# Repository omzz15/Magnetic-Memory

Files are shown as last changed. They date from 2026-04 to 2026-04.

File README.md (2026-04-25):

*Note: Any time I say MAD, I am refering to the memory address.

# Overview

Magnetic-core memory was an early form of non-volatile random access memory (RAM) used in early computing, notably the Apollo Guidance Computers. I am working with a friend to create our own magnetic core memory to interface with an 8-bit computer. This repository contains the code, schematics, and PCBs we make. Currently, we have made the schematic and PCB for the logic component of the memory as well as code to emulate the rest of the memory and interface with computers through serial. This is still a work in progress and has a long way to go but I thought I would share what I have.

TODO write updated docs

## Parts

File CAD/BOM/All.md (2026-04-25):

## Resistors(0603)
1. 10k: 32
2. 5.1k: 2
3. 1k: 2
4. 240: 43
5. 11: 16
6. 1K5: 24
7. 1K2: 16
8. 1K8: 16

9. 10: 32

## Capacitors(0603)
1. 220p: 2
2. 1000p: 2
3. 1u: 17
4. 10u: 40

## Other
1. 74HC4514PW,118(demux): 2
2. 74AHC123AD,118(multivibrator): 2
3. SN74LVC1G08DBVR-EV(AND): 1
4. MC74VHC1G32DFT1G-L22038(OR): 1
5. GSFC0201 (N-CH MOS)(SOT-23): 48
6. DMC2710UDW-7(MOSFET N/P-CH)(SOT-363): 64
7. SN74HCS32PWR(OR 4ch): 2
8. SN74AHC240PWR(8-Bit inverter): 1
9. HEF4043BT,653(SR latch 4ch): 2
10. LM393A-SR (Comparator)(8-SOIC 3.9mm): 8

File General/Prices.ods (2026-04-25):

Buying
Function | Part # | Part Description | Digikey # | Unit Price | Qty. | Total | Supply Capacitance | Grand Total: | 5.66
8 Bit Inverter | SN74AHC240PWR | 2 x 4 bit inverter w/ tri state output | 296-4582-1-ND | $0.53 | 1 | $0.53
2x 4 Bit Memory Register & Demux | CD4514BM96 | 4 Bit Demux w/ latch | 296-31529-1-ND | $0.91 | 2 | $1.82
8 Bit Latch / Register & Tri-state Buffer | HEF4043BT,653 | 4 Bit SR Latch w/ 3 state output | 1727-1799-1-ND | $0.58 | 2 | $1.16
2x Pulse EN & Pulse Reset | 74AHC123AD,118 | 2 ch Monostable Multivibrator | 1727-7290-1-ND | $0.41 | 2 | $0.82
Y EN Trigger Delay Resistor | ERA-6AEB181V | 180 ohm 1/8 watt 0805 resistor 0.1% tol | P180DACT-ND | $0.13 | 1 | $0.13
Y EN Trigger Delay Capacitor | GMC21CG102F50NT | 1nF 0805 MLCC 1% tol | 4713-GMC21CG102F50NTCT-ND | $0.13 | 1 | $0.13
X/Y EN Pulse Resistor | ERA-6AEB471V | 470 ohm 1/8 watt 0805 resistor 0.1% tol | P470DACT-ND | $0.13 | 2 | $0.26
X/Y EN Pulse Capacitor | C0805C103J5RAC7210 | 10nF 0805 MLCC 5% tol | 399-17616-1-ND | $0.10 | 2 | $0.20
SR Reset Pulse Resistor | ERA-6AEB222V | 2.2k ohm 1/8 watt 0805 resistor 0.1% tol | P2.2KDACT-ND | $0.13 | 1 | $0.13
SR Reset Pulse Capacitor | C0805C101G5HAC7800 | 0.1nF 0805 MLCC 2% tol | 399-C0805C101G5HAC7800CT-ND | $0.14 | 1 | $0.14
EN Pulse Trigger | SN74LVC1G32DBVR | High power OR Gate | 296-9847-1-ND | $0.34 | 1 | $0.34
Finding
 |  | 2.2k ohm potentiometer (0.1in spacing) |  |  | 1
 |  | 1.5k ohm potentiometer (0.1in spacing) |  |  | 2
 |  | 10nf 0603 power caps
Tri-state Buffer | M74HCT245TTR | 8 Bit Transceiver | 497-8195-1-ND | $0.34 | 0 | $0.00

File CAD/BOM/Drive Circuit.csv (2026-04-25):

Id | Designator | Footprint | Quantity | Designation | Supplier and ref
1 | Q52,Q10,Q82,Q46,Q79,Q19,Q34,Q16,Q25,Q28,Q49,Q67,Q61,Q1,Q73,Q70,Q7,Q76,Q64,Q88,Q31,Q4,Q43,Q58,Q13,Q40,Q37,Q85,Q55,Q91,Q22,Q94 | SOT-23 | 32 | 2N7002E
2 | Y1,X1,X2,Y2 | PinHeader_1x16_P2.54mm_Vertical | 4 | Conn_01x16
3 | Q77,Q81,Q24,Q57,Q44,Q78,Q87,Q54,Q5,Q93,Q51,Q38,Q41,Q11,Q92,Q80,Q60,Q20,Q66,Q53,Q86,Q23,Q35,Q3,Q72,Q36,Q48,Q27,Q18,Q83,Q33,Q14,Q2,Q30,Q21,Q45,Q90,Q89,Q84,Q96,Q9,Q6,Q71,Q17,Q56,Q32,Q8,Q47,Q29,Q15,Q63,Q75,Q68,Q26,Q69,Q59,Q12,Q50,Q65,Q74,Q95,Q62,Q42,Q39 | SOT65P210X110-6N | 64 | DMC2710UDW-7
4 | R14,R10,R26,R32,R27,R19,R17,R31,R24,R30,R23,R22,R18,R12,R25,R3,R6,R20,R7,R2,R9,R8,R4,R34,R28,R5,R29,R1,R33,R21,R11,R16,R13,R15 | R_0603_1608Metric_Pad0.98x0.95mm_HandSolder | 34 | 240
5 | MADX1,MADY2,MADX2,MADY1 | PinHeader_1x08_P2.54mm_Vertical | 4 | Conn_01x08
6 | PWR1,DAT1 | PinHeader_1x02_P2.54mm_Vertical | 2 | Conn_01x02
7 | C29,C2,C8,C32,C23,C28,C15,C10,C16,C19,C21,C17,C20,C5,C7,C6,C30,C11,C27,C4,C12,C31,C22,C1,C24,C14,C18,C3,C26,C13,C25,C9 | C_0603_1608Metric_Pad1.08x0.95mm_HandSolder | 32 | 10u

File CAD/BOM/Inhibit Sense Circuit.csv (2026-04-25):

Id | Designator | Footprint | Quantity | Designation | Supplier and ref
1 | R56,R30,R74,R85,R24,R59,R65,R33,R39,R82,R15,R21,R45,R68,R12,R77 | R_0603_1608Metric_Pad0.98x0.95mm_HandSolder | 16 | 11
2 | IS8,IS1,IS5,IS4,IS7,J2,IS2,IS3,IS6 | PinHeader_1x02_P2.54mm_Vertical | 9 | Conn_01x02
3 | IC3,IC5 | SOP65P640X120-14N | 2 | SN74HCS32PWR
4 | R72,R75,R28,R37,R78,R9,R60,R16,R31,R53,R66,R69,R63,R25,R57,R47,R19,R41,R34,R13,R86,R83,R10,R22 | R_0603_1608Metric_Pad0.98x0.95mm_HandSolder | 24 | 1K5
5 | Q5,Q8,Q1,Q14,Q11,Q7,Q10,Q3,Q2,Q4,Q15,Q13,Q6,Q12,Q16,Q9 | SOT-23 | 16 | 2N7002E
6 | U6,U8,U1,U5,U2,U4,U7,U3 | SO1SOP-8-A_TPK | 8 | LM393
7 | R71,R51,R36,R35,R88,R87,R27,R62,R61,R26,R80,R17,R49,R18,R70,R79 | R_0603_1608Metric_Pad0.98x0.95mm_HandSolder | 16 | 1K2
8 | R64,R55,R76,R38,R20,R84,R43,R11,R32,R29,R67,R14,R23,R73,R58,R81 | R_0603_1608Metric_Pad0.98x0.95mm_HandSolder | 16 | 1K8
9 | R1,R54,R42,R46,R40,R50,R52,R48,R44 | R_0603_1608Metric_Pad0.98x0.95mm_HandSolder | 9 | 240
10 | IC1,IC2 | HEF4043BT653 | 2 | HEF4043BT,653
11 | IC4 | SOP65P640X120-20N | 1 | SN74AHC240PWR
12 | J1 | PinHeader_1x13_P2.54mm_Vertical | 1 | Conn_01x13
13 | C9,C48,C14,C15,C12,C10,C13,C11 | C_0603_1608Metric_Pad1.08x0.95mm_HandSolder | 8 | 10u
14 | C19,C3,C8,C20,C18,C17,C2,C6,C16,C7,C4,C5,C1 | C_0603_1608Metric_Pad1.08x0.95mm_HandSolder | 13 | 1u

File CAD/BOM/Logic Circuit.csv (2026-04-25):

Id | Designator | Footprint | Quantity | Designation | Supplier and ref
1 | R24,R37,R14,R2,R34,R25,R41,R3,R40,R32,R16,R8,R35,R1,R26,R38,R18,R30,R15,R36,R29,R4,R28,R33,R17,R22,R31,R27,R21,R23,R11,R6 | R_0603_1608Metric_Pad0.98x0.95mm_HandSolder | 32 | 10k
2 | C4,C3 | C_0603_1608Metric_Pad1.08x0.95mm_HandSolder | 2 | 220p
3 | C2,C1 | C_0603_1608Metric_Pad1.08x0.95mm_HandSolder | 2 | 1000p
4 | IC3,IC1 | SOP65P640X110-24N | 2 | 74HC4514PW,118
5 | R42,R43 | R_0603_1608Metric_Pad0.98x0.95mm_HandSolder | 2 | 5.1k
6 | IS_OUT1,IN1 | PinHeader_1x13_P2.54mm_Vertical | 2 | Conn_01x13
7 | RV1,RV3,RV2 | Potentiometer_Bourns_3296W_Vertical | 3 | R_Potentiometer
8 | IC5,IC4 | SOIC127P600X175-16N | 2 | 74AHC123AD,118
9 | Y1,X2,Y2,X1 | PinHeader_1x08_P2.54mm_Vertical | 4 | Conn_01x08
10 | C7,C8,C9,C6 | C_0603_1608Metric_Pad1.08x0.95mm_HandSolder | 4 | 1u
11 | D_DAT1 | PinSocket_1x02_P2.54mm_Vertical | 1 | Conn_01x02
12 | PULSE_DBG1 | PinSocket_1x06_P2.54mm_Vertical | 1 | Conn_01x06
13 | R39,R44 | R_0603_1608Metric_Pad0.98x0.95mm_HandSolder | 2 | 1k
14 | U2 | SOT-23-5_HandSoldering | 1 | SN74LVC1G08DBVR-EV
15 | U1 | SOT-353_SC-70-5_Handsoldering | 1 | MC74VHC1G32DFT1G-L22038

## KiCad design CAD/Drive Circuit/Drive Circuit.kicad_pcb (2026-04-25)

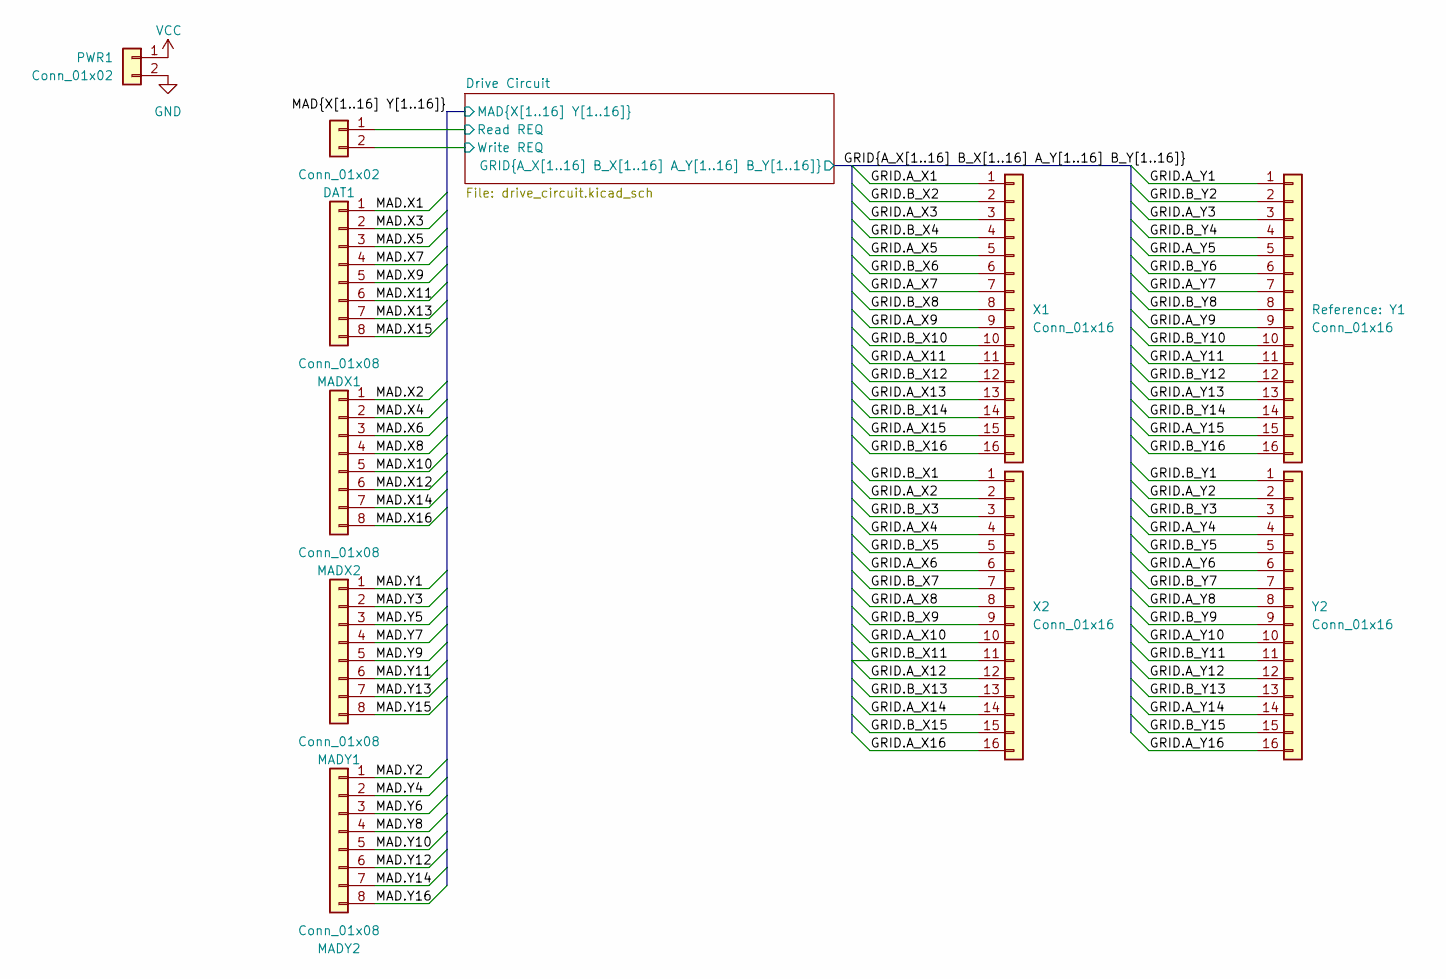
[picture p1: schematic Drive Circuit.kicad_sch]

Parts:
DAT1: Conn_01x02; PinHeader_1x02_P2.54mm_Vertical
MADX1, MADX2: Conn_01x08; PinHeader_1x08_P2.54mm_Vertical
MADY1, MADY2: Conn_01x08; PinHeader_1x08_P2.54mm_Vertical
PWR1: Conn_01x02; PinHeader_1x02_P2.54mm_Vertical
X1, X2: Conn_01x16; PinHeader_1x16_P2.54mm_Vertical
Y1, Y2: Conn_01x16; PinHeader_1x16_P2.54mm_Vertical

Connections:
/Drive Circuit/Read REQ: DAT1.1; also elsewhere on the board
/Drive Circuit/Write REQ: DAT1.2; also elsewhere on the board
/GRID.A_X1: X1.1; also elsewhere on the board
/GRID.A_X2: X2.2; also elsewhere on the board
/GRID.A_X3: X1.3; also elsewhere on the board
/GRID.A_X4: X2.4; also elsewhere on the board
/GRID.A_X5: X1.5; also elsewhere on the board
/GRID.A_X6: X2.6; also elsewhere on the board
/GRID.A_X7: X1.7; also elsewhere on the board
/GRID.A_X8: X2.8; also elsewhere on the board
/GRID.A_X9: X1.9; also elsewhere on the board
/GRID.A_X10: X2.10; also elsewhere on the board
/GRID.A_X11: X1.11; also elsewhere on the board
/GRID.A_X12: X2.12; also elsewhere on the board
/GRID.A_X13: X1.13; also elsewhere on the board
/GRID.A_X14: X2.14; also elsewhere on the board
/GRID.A_X15: X1.15; also elsewhere on the board
/GRID.A_X16: X2.16; also elsewhere on the board
/GRID.A_Y1: Y1.1; also elsewhere on the board
/GRID.A_Y2: Y2.2; also elsewhere on the board
/GRID.A_Y3: Y1.3; also elsewhere on the board
/GRID.A_Y4: Y2.4; also elsewhere on the board
/GRID.A_Y5: Y1.5; also elsewhere on the board
/GRID.A_Y6: Y2.6; also elsewhere on the board
/GRID.A_Y7: Y1.7; also elsewhere on the board
/GRID.A_Y8: Y2.8; also elsewhere on the board
/GRID.A_Y9: Y1.9; also elsewhere on the board
/GRID.A_Y10: Y2.10; also elsewhere on the board
/GRID.A_Y11: Y1.11; also elsewhere on the board
/GRID.A_Y12: Y2.12; also elsewhere on the board
/GRID.A_Y13: Y1.13; also elsewhere on the board
/GRID.A_Y14: Y2.14; also elsewhere on the board
/GRID.A_Y15: Y1.15; also elsewhere on the board
/GRID.A_Y16: Y2.16; also elsewhere on the board
/GRID.B_X1: X2.1; also elsewhere on the board
/GRID.B_X2: X1.2; also elsewhere on the board
/GRID.B_X3: X2.3; also elsewhere on the board
/GRID.B_X4: X1.4; also elsewhere on the board
/GRID.B_X5: X2.5; also elsewhere on the board
/GRID.B_X6: X1.6; also elsewhere on the board
/GRID.B_X7: X2.7; also elsewhere on the board
/GRID.B_X8: X1.8; also elsewhere on the board
/GRID.B_X9: X2.9; also elsewhere on the board
/GRID.B_X10: X1.10; also elsewhere on the board
/GRID.B_X11: X2.11; also elsewhere on the board
/GRID.B_X12: X1.12; also elsewhere on the board
/GRID.B_X13: X2.13; also elsewhere on the board
/GRID.B_X14: X1.14; also elsewhere on the board
/GRID.B_X15: X2.15; also elsewhere on the board
/GRID.B_X16: X1.16; also elsewhere on the board
/GRID.B_Y1: Y2.1; also elsewhere on the board
/GRID.B_Y2: Y1.2; also elsewhere on the board
/GRID.B_Y3: Y2.3; also elsewhere on the board
/GRID.B_Y4: Y1.4; also elsewhere on the board
/GRID.B_Y5: Y2.5; also elsewhere on the board
/GRID.B_Y6: Y1.6; also elsewhere on the board
/GRID.B_Y7: Y2.7; also elsewhere on the board
/GRID.B_Y8: Y1.8; also elsewhere on the board
/GRID.B_Y9: Y2.9; also elsewhere on the board
/GRID.B_Y10: Y1.10; also elsewhere on the board
/GRID.B_Y11: Y2.11; also elsewhere on the board
/GRID.B_Y12: Y1.12; also elsewhere on the board
/GRID.B_Y13: Y2.13; also elsewhere on the board
/GRID.B_Y14: Y1.14; also elsewhere on the board
/GRID.B_Y15: Y2.15; also elsewhere on the board
/GRID.B_Y16: Y1.16; also elsewhere on the board
/MAD.X1: MADX1.1; also elsewhere on the board
/MAD.X2: MADX2.1; also elsewhere on the board
/MAD.X3: MADX1.2; also elsewhere on the board
/MAD.X4: MADX2.2; also elsewhere on the board
/MAD.X5: MADX1.3; also elsewhere on the board
/MAD.X6: MADX2.3; also elsewhere on the board
/MAD.X7: MADX1.4; also elsewhere on the board
/MAD.X8: MADX2.4; also elsewhere on the board
/MAD.X9: MADX1.5; also elsewhere on the board
/MAD.X10: MADX2.5; also elsewhere on the board
/MAD.X11: MADX1.6; also elsewhere on the board
/MAD.X12: MADX2.6; also elsewhere on the board
/MAD.X13: MADX1.7; also elsewhere on the board
/MAD.X14: MADX2.7; also elsewhere on the board
/MAD.X15: MADX1.8; also elsewhere on the board
/MAD.X16: MADX2.8; also elsewhere on the board
/MAD.Y1: MADY1.1; also elsewhere on the board
/MAD.Y2: MADY2.1; also elsewhere on the board
/MAD.Y3: MADY1.2; also elsewhere on the board
/MAD.Y4: MADY2.2; also elsewhere on the board
/MAD.Y5: MADY1.3; also elsewhere on the board
/MAD.Y6: MADY2.3; also elsewhere on the board
/MAD.Y7: MADY1.4; also elsewhere on the board
/MAD.Y8: MADY2.4; also elsewhere on the board
/MAD.Y9: MADY1.5; also elsewhere on the board
/MAD.Y10: MADY2.5; also elsewhere on the board
/MAD.Y11: MADY1.6; also elsewhere on the board
/MAD.Y12: MADY2.6; also elsewhere on the board
/MAD.Y13: MADY1.7; also elsewhere on the board
/MAD.Y14: MADY2.7; also elsewhere on the board
/MAD.Y15: MADY1.8; also elsewhere on the board
/MAD.Y16: MADY2.8; also elsewhere on the board
GND: PWR1.2; also elsewhere on the board
VCC: PWR1.1; also elsewhere on the board

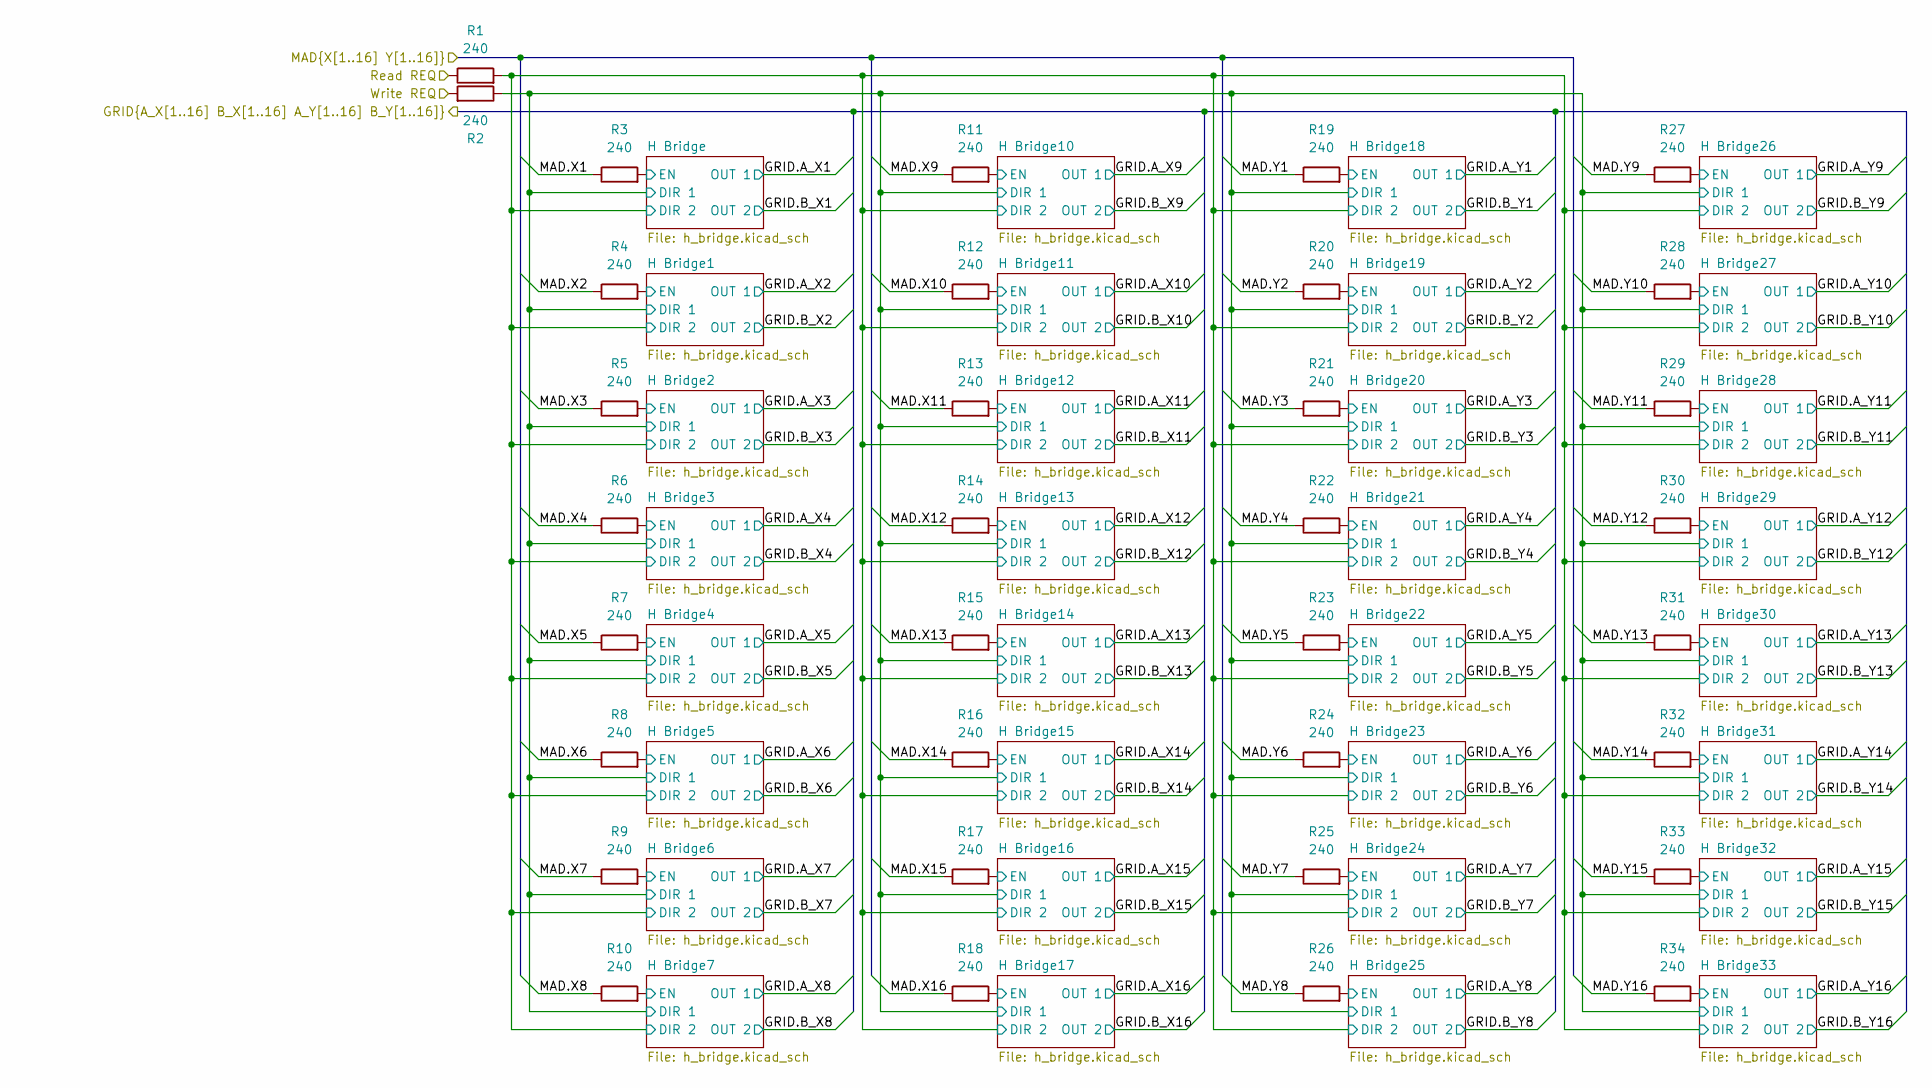
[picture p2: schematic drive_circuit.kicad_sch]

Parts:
R1, R2, R3, R4, R5, R6, R7, R8, R9, R10, R11, R12, R13, R14, R15, R16, R17, R18, R19, R20, R21, R22, R23, R24, R25, R26, R27, R28, R29, R30, R31, R32, R33, R34: 240; R_0603_1608Metric_Pad0.98x0.95mm_HandSolder

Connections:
/Drive Circuit/H Bridge1/EN: R4.2; also elsewhere on the board
/Drive Circuit/H Bridge2/EN: R5.2; also elsewhere on the board
/Drive Circuit/H Bridge3/EN: R6.2; also elsewhere on the board
/Drive Circuit/H Bridge4/EN: R7.2; also elsewhere on the board
/Drive Circuit/H Bridge5/EN: R8.2; also elsewhere on the board
/Drive Circuit/H Bridge6/EN: R9.2; also elsewhere on the board
/Drive Circuit/H Bridge7/EN: R10.2; also elsewhere on the board
/Drive Circuit/H Bridge10/EN: R11.2; also elsewhere on the board
/Drive Circuit/H Bridge11/EN: R12.2; also elsewhere on the board
/Drive Circuit/H Bridge12/EN: R13.2; also elsewhere on the board
/Drive Circuit/H Bridge13/EN: R14.2; also elsewhere on the board
/Drive Circuit/H Bridge14/EN: R15.2; also elsewhere on the board
/Drive Circuit/H Bridge15/EN: R16.2; also elsewhere on the board
/Drive Circuit/H Bridge16/EN: R17.2; also elsewhere on the board
/Drive Circuit/H Bridge17/EN: R18.2; also elsewhere on the board
/Drive Circuit/H Bridge18/EN: R19.2; also elsewhere on the board
/Drive Circuit/H Bridge19/EN: R20.2; also elsewhere on the board
/Drive Circuit/H Bridge20/EN: R21.2; also elsewhere on the board
/Drive Circuit/H Bridge21/EN: R22.2; also elsewhere on the board
/Drive Circuit/H Bridge22/EN: R23.2; also elsewhere on the board
/Drive Circuit/H Bridge23/EN: R24.2; also elsewhere on the board
/Drive Circuit/H Bridge24/EN: R25.2; also elsewhere on the board
/Drive Circuit/H Bridge25/EN: R26.2; also elsewhere on the board
/Drive Circuit/H Bridge26/EN: R27.2; also elsewhere on the board
/Drive Circuit/H Bridge27/EN: R28.2; also elsewhere on the board
/Drive Circuit/H Bridge28/EN: R29.2; also elsewhere on the board
/Drive Circuit/H Bridge29/EN: R30.2; also elsewhere on the board
/Drive Circuit/H Bridge30/EN: R31.2; also elsewhere on the board
/Drive Circuit/H Bridge31/EN: R32.2; also elsewhere on the board
/Drive Circuit/H Bridge32/EN: R33.2; also elsewhere on the board
/Drive Circuit/H Bridge33/EN: R34.2; also elsewhere on the board
/Drive Circuit/H Bridge/DIR 1: R2.1; also elsewhere on the board
/Drive Circuit/H Bridge/DIR 2: R1.2; also elsewhere on the board
/Drive Circuit/H Bridge/EN: R3.2; also elsewhere on the board
/Drive Circuit/Read REQ: R1.1; also elsewhere on the board
/Drive Circuit/Write REQ: R2.2; also elsewhere on the board
/MAD.X1: R3.1; also elsewhere on the board
/MAD.X2: R4.1; also elsewhere on the board
/MAD.X3: R5.1; also elsewhere on the board
/MAD.X4: R6.1; also elsewhere on the board
/MAD.X5: R7.1; also elsewhere on the board
/MAD.X6: R8.1; also elsewhere on the board
/MAD.X7: R9.1; also elsewhere on the board
/MAD.X8: R10.1; also elsewhere on the board
/MAD.X9: R11.1; also elsewhere on the board
/MAD.X10: R12.1; also elsewhere on the board
/MAD.X11: R13.1; also elsewhere on the board
/MAD.X12: R14.1; also elsewhere on the board
/MAD.X13: R15.1; also elsewhere on the board
/MAD.X14: R16.1; also elsewhere on the board
/MAD.X15: R17.1; also elsewhere on the board
/MAD.X16: R18.1; also elsewhere on the board
/MAD.Y1: R19.1; also elsewhere on the board
/MAD.Y2: R20.1; also elsewhere on the board
/MAD.Y3: R21.1; also elsewhere on the board
/MAD.Y4: R22.1; also elsewhere on the board
/MAD.Y5: R23.1; also elsewhere on the board
/MAD.Y6: R24.1; also elsewhere on the board
/MAD.Y7: R25.1; also elsewhere on the board
/MAD.Y8: R26.1; also elsewhere on the board
/MAD.Y9: R27.1; also elsewhere on the board
/MAD.Y10: R28.1; also elsewhere on the board
/MAD.Y11: R29.1; also elsewhere on the board
/MAD.Y12: R30.1; also elsewhere on the board
/MAD.Y13: R31.1; also elsewhere on the board
/MAD.Y14: R32.1; also elsewhere on the board
/MAD.Y15: R33.1; also elsewhere on the board
/MAD.Y16: R34.1; also elsewhere on the board

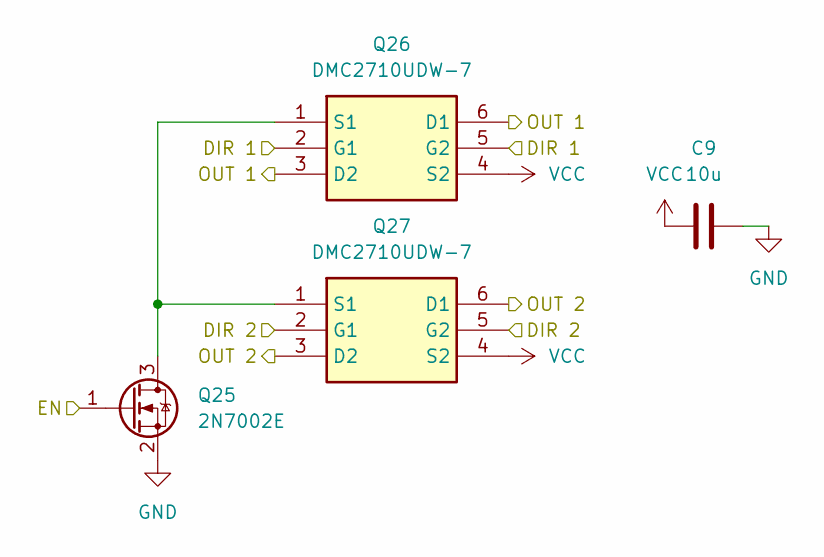
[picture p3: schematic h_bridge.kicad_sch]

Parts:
C9: 10u; C_0603_1608Metric_Pad1.08x0.95mm_HandSolder
Q25: 2N7002E; SOT-23
Q26, Q27: DMC2710UDW-7; SOT65P210X110-6N; Mouser Part Number 621-DMC2710UDW-7

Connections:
/Drive Circuit/H Bridge11/EN: Q25.1 (G); also elsewhere on the board
/Drive Circuit/H Bridge/DIR 1: Q26.2 (G1), Q26.5 (G2); also elsewhere on the board
/Drive Circuit/H Bridge/DIR 2: Q27.2 (G1), Q27.5 (G2); also elsewhere on the board
/GRID.A_X10: Q26.3 (D2), Q26.6 (D1); also elsewhere on the board
/GRID.B_X10: Q27.3 (D2), Q27.6 (D1); also elsewhere on the board
GND: C9.1, Q25.2 (S); also elsewhere on the board
unnamed: Q25.3 (D), Q26.1 (S1), Q27.1 (S1)
VCC: C9.2, Q26.4 (S2), Q27.4 (S2); also elsewhere on the board

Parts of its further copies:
C1, C2, C3, C4, C5, C6, C7, C8, C10, C11, C12, C13, C14, C15, C16, C17, C18, C19, C20, C21, C22, C23, C24, C25, C26, C27, C28, C29, C30, C31, C32: 10u; C_0603_1608Metric_Pad1.08x0.95mm_HandSolder
Q1, Q4, Q7, Q10, Q13, Q16, Q19, Q22, Q28, Q31, Q34, Q37, Q40, Q43, Q46, Q49, Q52, Q55, Q58, Q61, Q64, Q67, Q70, Q73, Q76, Q79, Q82, Q85, Q88, Q91, Q94: 2N7002E; SOT-23
Q2, Q3, Q5, Q6, Q8, Q9, Q11, Q12, Q14, Q15, Q17, Q18, Q20, Q21, Q23, Q24, Q29, Q30, Q32, Q33, Q35, Q36, Q38, Q39, Q41, Q42, Q44, Q45, Q47, Q48, Q50, Q51, Q53, Q54, Q56, Q57, Q59, Q60, Q62, Q63, Q65, Q66, Q68, Q69, Q71, Q72, Q74, Q75, Q77, Q78, Q80, Q81, Q83, Q84, Q86, Q87, Q89, Q90, Q92, Q93, Q95, Q96: DMC2710UDW-7; SOT65P210X110-6N; Mouser Part Number 621-DMC2710UDW-7

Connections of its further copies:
/Drive Circuit/H Bridge1/EN: Q40.1 (G); also elsewhere on the board
/Drive Circuit/H Bridge2/EN: Q34.1 (G); also elsewhere on the board
/Drive Circuit/H Bridge3/EN: Q82.1 (G); also elsewhere on the board
/Drive Circuit/H Bridge4/EN: Q85.1 (G); also elsewhere on the board
/Drive Circuit/H Bridge5/EN: Q79.1 (G); also elsewhere on the board
/Drive Circuit/H Bridge6/EN: Q76.1 (G); also elsewhere on the board
/Drive Circuit/H Bridge7/EN: Q73.1 (G); also elsewhere on the board
/Drive Circuit/H Bridge10/EN: Q31.1 (G); also elsewhere on the board
/Drive Circuit/H Bridge12/EN: Q28.1 (G); also elsewhere on the board
/Drive Circuit/H Bridge13/EN: Q70.1 (G); also elsewhere on the board
/Drive Circuit/H Bridge14/EN: Q67.1 (G); also elsewhere on the board
/Drive Circuit/H Bridge15/EN: Q88.1 (G); also elsewhere on the board
/Drive Circuit/H Bridge16/EN: Q91.1 (G); also elsewhere on the board
/Drive Circuit/H Bridge17/EN: Q94.1 (G); also elsewhere on the board
/Drive Circuit/H Bridge18/EN: Q13.1 (G); also elsewhere on the board
/Drive Circuit/H Bridge19/EN: Q16.1 (G); also elsewhere on the board
/Drive Circuit/H Bridge20/EN: Q22.1 (G); also elsewhere on the board
/Drive Circuit/H Bridge21/EN: Q19.1 (G); also elsewhere on the board
/Drive Circuit/H Bridge22/EN: Q46.1 (G); also elsewhere on the board
/Drive Circuit/H Bridge23/EN: Q43.1 (G); also elsewhere on the board
/Drive Circuit/H Bridge24/EN: Q52.1 (G); also elsewhere on the board
/Drive Circuit/H Bridge25/EN: Q49.1 (G); also elsewhere on the board
/Drive Circuit/H Bridge26/EN: Q4.1 (G); also elsewhere on the board
/Drive Circuit/H Bridge27/EN: Q1.1 (G); also elsewhere on the board
/Drive Circuit/H Bridge28/EN: Q7.1 (G); also elsewhere on the board
/Drive Circuit/H Bridge29/EN: Q10.1 (G); also elsewhere on the board
/Drive Circuit/H Bridge30/EN: Q55.1 (G); also elsewhere on the board
/Drive Circuit/H Bridge31/EN: Q61.1 (G); also elsewhere on the board
/Drive Circuit/H Bridge32/EN: Q64.1 (G); also elsewhere on the board
/Drive Circuit/H Bridge33/EN: Q58.1 (G); also elsewhere on the board
/Drive Circuit/H Bridge/DIR 1: Q2.2 (G1), Q2.5 (G2), Q5.2 (G1), Q5.5 (G2), Q8.2 (G1), Q8.5 (G2), Q11.2 (G1), Q11.5 (G2), Q14.2 (G1), Q14.5 (G2), Q17.2 (G1), Q17.5 (G2), Q20.2 (G1), Q20.5 (G2), Q23.2 (G1), Q23.5 (G2), Q29.2 (G1), Q29.5 (G2), Q32.2 (G1), Q32.5 (G2), Q35.2 (G1), Q35.5 (G2), Q38.2 (G1), Q38.5 (G2), Q41.2 (G1), Q41.5 (G2), Q44.2 (G1), Q44.5 (G2), Q47.2 (G1), Q47.5 (G2), Q50.2 (G1), Q50.5 (G2), Q53.2 (G1), Q53.5 (G2), Q56.2 (G1), Q56.5 (G2), Q59.2 (G1), Q59.5 (G2), Q62.2 (G1), Q62.5 (G2), Q65.2 (G1), Q65.5 (G2), Q68.2 (G1), Q68.5 (G2), Q71.2 (G1), Q71.5 (G2), Q74.2 (G1), Q74.5 (G2), Q77.2 (G1), Q77.5 (G2), Q80.2 (G1), Q80.5 (G2), Q83.2 (G1), Q83.5 (G2), Q86.2 (G1), Q86.5 (G2), Q89.2 (G1), Q89.5 (G2), Q92.2 (G1), Q92.5 (G2), Q95.2 (G1), Q95.5 (G2); also elsewhere on the board
/Drive Circuit/H Bridge/DIR 2: Q3.2 (G1), Q3.5 (G2), Q6.2 (G1), Q6.5 (G2), Q9.2 (G1), Q9.5 (G2), Q12.2 (G1), Q12.5 (G2), Q15.2 (G1), Q15.5 (G2), Q18.2 (G1), Q18.5 (G2), Q21.2 (G1), Q21.5 (G2), Q24.2 (G1), Q24.5 (G2), Q30.2 (G1), Q30.5 (G2), Q33.2 (G1), Q33.5 (G2), Q36.2 (G1), Q36.5 (G2), Q39.2 (G1), Q39.5 (G2), Q42.2 (G1), Q42.5 (G2), Q45.2 (G1), Q45.5 (G2), Q48.2 (G1), Q48.5 (G2), Q51.2 (G1), Q51.5 (G2), Q54.2 (G1), Q54.5 (G2), Q57.2 (G1), Q57.5 (G2), Q60.2 (G1), Q60.5 (G2), Q63.2 (G1), Q63.5 (G2), Q66.2 (G1), Q66.5 (G2), Q69.2 (G1), Q69.5 (G2), Q72.2 (G1), Q72.5 (G2), Q75.2 (G1), Q75.5 (G2), Q78.2 (G1), Q78.5 (G2), Q81.2 (G1), Q81.5 (G2), Q84.2 (G1), Q84.5 (G2), Q87.2 (G1), Q87.5 (G2), Q90.2 (G1), Q90.5 (G2), Q93.2 (G1), Q93.5 (G2), Q96.2 (G1), Q96.5 (G2); also elsewhere on the board
/Drive Circuit/H Bridge/EN: Q37.1 (G); also elsewhere on the board
/GRID.A_X1: Q38.3 (D2), Q38.6 (D1); also elsewhere on the board
/GRID.A_X2: Q41.3 (D2), Q41.6 (D1); also elsewhere on the board
/GRID.A_X3: Q35.3 (D2), Q35.6 (D1); also elsewhere on the board
/GRID.A_X4: Q83.3 (D2), Q83.6 (D1); also elsewhere on the board
/GRID.A_X5: Q86.3 (D2), Q86.6 (D1); also elsewhere on the board
/GRID.A_X6: Q80.3 (D2), Q80.6 (D1); also elsewhere on the board
/GRID.A_X7: Q77.3 (D2), Q77.6 (D1); also elsewhere on the board
/GRID.A_X8: Q74.3 (D2), Q74.6 (D1); also elsewhere on the board
/GRID.A_X9: Q32.3 (D2), Q32.6 (D1); also elsewhere on the board
/GRID.A_X11: Q29.3 (D2), Q29.6 (D1); also elsewhere on the board
/GRID.A_X12: Q71.3 (D2), Q71.6 (D1); also elsewhere on the board
/GRID.A_X13: Q68.3 (D2), Q68.6 (D1); also elsewhere on the board
/GRID.A_X14: Q89.3 (D2), Q89.6 (D1); also elsewhere on the board
/GRID.A_X15: Q92.3 (D2), Q92.6 (D1); also elsewhere on the board
/GRID.A_X16: Q95.3 (D2), Q95.6 (D1); also elsewhere on the board
/GRID.A_Y1: Q14.3 (D2), Q14.6 (D1); also elsewhere on the board
/GRID.A_Y2: Q17.3 (D2), Q17.6 (D1); also elsewhere on the board
/GRID.A_Y3: Q23.3 (D2), Q23.6 (D1); also elsewhere on the board
/GRID.A_Y4: Q20.3 (D2), Q20.6 (D1); also elsewhere on the board
/GRID.A_Y5: Q47.3 (D2), Q47.6 (D1); also elsewhere on the board
/GRID.A_Y6: Q44.3 (D2), Q44.6 (D1); also elsewhere on the board
/GRID.A_Y7: Q53.3 (D2), Q53.6 (D1); also elsewhere on the board
/GRID.A_Y8: Q50.3 (D2), Q50.6 (D1); also elsewhere on the board
/GRID.A_Y9: Q5.3 (D2), Q5.6 (D1); also elsewhere on the board
/GRID.A_Y10: Q2.3 (D2), Q2.6 (D1); also elsewhere on the board
/GRID.A_Y11: Q8.3 (D2), Q8.6 (D1); also elsewhere on the board
/GRID.A_Y12: Q11.3 (D2), Q11.6 (D1); also elsewhere on the board
/GRID.A_Y13: Q56.3 (D2), Q56.6 (D1); also elsewhere on the board
/GRID.A_Y14: Q62.3 (D2), Q62.6 (D1); also elsewhere on the board
/GRID.A_Y15: Q65.3 (D2), Q65.6 (D1); also elsewhere on the board
/GRID.A_Y16: Q59.3 (D2), Q59.6 (D1); also elsewhere on the board
/GRID.B_X1: Q39.3 (D2), Q39.6 (D1); also elsewhere on the board
/GRID.B_X2: Q42.3 (D2), Q42.6 (D1); also elsewhere on the board
/GRID.B_X3: Q36.3 (D2), Q36.6 (D1); also elsewhere on the board
/GRID.B_X4: Q84.3 (D2), Q84.6 (D1); also elsewhere on the board
/GRID.B_X5: Q87.3 (D2), Q87.6 (D1); also elsewhere on the board
/GRID.B_X6: Q81.3 (D2), Q81.6 (D1); also elsewhere on the board
/GRID.B_X7: Q78.3 (D2), Q78.6 (D1); also elsewhere on the board
/GRID.B_X8: Q75.3 (D2), Q75.6 (D1); also elsewhere on the board
/GRID.B_X9: Q33.3 (D2), Q33.6 (D1); also elsewhere on the board
/GRID.B_X11: Q30.3 (D2), Q30.6 (D1); also elsewhere on the board
/GRID.B_X12: Q72.3 (D2), Q72.6 (D1); also elsewhere on the board
/GRID.B_X13: Q69.3 (D2), Q69.6 (D1); also elsewhere on the board
/GRID.B_X14: Q90.3 (D2), Q90.6 (D1); also elsewhere on the board
/GRID.B_X15: Q93.3 (D2), Q93.6 (D1); also elsewhere on the board
/GRID.B_X16: Q96.3 (D2), Q96.6 (D1); also elsewhere on the board
/GRID.B_Y1: Q15.3 (D2), Q15.6 (D1); also elsewhere on the board
/GRID.B_Y2: Q18.3 (D2), Q18.6 (D1); also elsewhere on the board
/GRID.B_Y3: Q24.3 (D2), Q24.6 (D1); also elsewhere on the board
/GRID.B_Y4: Q21.3 (D2), Q21.6 (D1); also elsewhere on the board
/GRID.B_Y5: Q48.3 (D2), Q48.6 (D1); also elsewhere on the board
/GRID.B_Y6: Q45.3 (D2), Q45.6 (D1); also elsewhere on the board
/GRID.B_Y7: Q54.3 (D2), Q54.6 (D1); also elsewhere on the board
/GRID.B_Y8: Q51.3 (D2), Q51.6 (D1); also elsewhere on the board
/GRID.B_Y9: Q6.3 (D2), Q6.6 (D1); also elsewhere on the board
/GRID.B_Y10: Q3.3 (D2), Q3.6 (D1); also elsewhere on the board
/GRID.B_Y11: Q9.3 (D2), Q9.6 (D1); also elsewhere on the board
/GRID.B_Y12: Q12.3 (D2), Q12.6 (D1); also elsewhere on the board
/GRID.B_Y13: Q57.3 (D2), Q57.6 (D1); also elsewhere on the board
/GRID.B_Y14: Q63.3 (D2), Q63.6 (D1); also elsewhere on the board
/GRID.B_Y15: Q66.3 (D2), Q66.6 (D1); also elsewhere on the board
/GRID.B_Y16: Q60.3 (D2), Q60.6 (D1); also elsewhere on the board
GND: C1.1, C2.1, C3.1, C4.1, C5.1, C6.1, C7.1, C8.1, C10.1, C11.1, C12.1, C13.1, C14.1, C15.1, C16.1, C17.1, C18.1, C19.1, C20.1, C21.1, C22.1, C23.1, C24.1, C25.1, C26.1, C27.1, C28.1, C29.1, C30.1, C31.1, C32.1, Q1.2 (S), Q4.2 (S), Q7.2 (S), Q10.2 (S), Q13.2 (S), Q16.2 (S), Q19.2 (S), Q22.2 (S), Q28.2 (S), Q31.2 (S), Q34.2 (S), Q37.2 (S), Q40.2 (S), Q43.2 (S), Q46.2 (S), Q49.2 (S), Q52.2 (S), Q55.2 (S), Q58.2 (S), Q61.2 (S), Q64.2 (S), Q67.2 (S), Q70.2 (S), Q73.2 (S), Q76.2 (S), Q79.2 (S), Q82.2 (S), Q85.2 (S), Q88.2 (S), Q91.2 (S), Q94.2 (S); also elsewhere on the board
unnamed: Q1.3 (D), Q2.1 (S1), Q3.1 (S1)
unnamed: Q4.3 (D), Q5.1 (S1), Q6.1 (S1)
unnamed: Q7.3 (D), Q8.1 (S1), Q9.1 (S1)
unnamed: Q10.3 (D), Q11.1 (S1), Q12.1 (S1)
unnamed: Q13.3 (D), Q14.1 (S1), Q15.1 (S1)
unnamed: Q16.3 (D), Q17.1 (S1), Q18.1 (S1)
unnamed: Q19.3 (D), Q20.1 (S1), Q21.1 (S1)
unnamed: Q22.3 (D), Q23.1 (S1), Q24.1 (S1)
unnamed: Q28.3 (D), Q29.1 (S1), Q30.1 (S1)
unnamed: Q31.3 (D), Q32.1 (S1), Q33.1 (S1)
unnamed: Q34.3 (D), Q35.1 (S1), Q36.1 (S1)
unnamed: Q37.3 (D), Q38.1 (S1), Q39.1 (S1)
unnamed: Q40.3 (D), Q41.1 (S1), Q42.1 (S1)
unnamed: Q43.3 (D), Q44.1 (S1), Q45.1 (S1)
unnamed: Q46.3 (D), Q47.1 (S1), Q48.1 (S1)
unnamed: Q49.3 (D), Q50.1 (S1), Q51.1 (S1)
unnamed: Q52.3 (D), Q53.1 (S1), Q54.1 (S1)
unnamed: Q55.3 (D), Q56.1 (S1), Q57.1 (S1)
unnamed: Q58.3 (D), Q59.1 (S1), Q60.1 (S1)
unnamed: Q61.3 (D), Q62.1 (S1), Q63.1 (S1)
unnamed: Q64.3 (D), Q65.1 (S1), Q66.1 (S1)
unnamed: Q67.3 (D), Q68.1 (S1), Q69.1 (S1)
unnamed: Q70.3 (D), Q71.1 (S1), Q72.1 (S1)
unnamed: Q73.3 (D), Q74.1 (S1), Q75.1 (S1)
unnamed: Q76.3 (D), Q77.1 (S1), Q78.1 (S1)
unnamed: Q79.3 (D), Q80.1 (S1), Q81.1 (S1)
unnamed: Q82.3 (D), Q83.1 (S1), Q84.1 (S1)
unnamed: Q85.3 (D), Q86.1 (S1), Q87.1 (S1)
unnamed: Q88.3 (D), Q89.1 (S1), Q90.1 (S1)
unnamed: Q91.3 (D), Q92.1 (S1), Q93.1 (S1)
unnamed: Q94.3 (D), Q95.1 (S1), Q96.1 (S1)
VCC: C1.2, C2.2, C3.2, C4.2, C5.2, C6.2, C7.2, C8.2, C10.2, C11.2, C12.2, C13.2, C14.2, C15.2, C16.2, C17.2, C18.2, C19.2, C20.2, C21.2, C22.2, C23.2, C24.2, C25.2, C26.2, C27.2, C28.2, C29.2, C30.2, C31.2, C32.2, Q2.4 (S2), Q3.4 (S2), Q5.4 (S2), Q6.4 (S2), Q8.4 (S2), Q9.4 (S2), Q11.4 (S2), Q12.4 (S2), Q14.4 (S2), Q15.4 (S2), Q17.4 (S2), Q18.4 (S2), Q20.4 (S2), Q21.4 (S2), Q23.4 (S2), Q24.4 (S2), Q29.4 (S2), Q30.4 (S2), Q32.4 (S2), Q33.4 (S2), Q35.4 (S2), Q36.4 (S2), Q38.4 (S2), Q39.4 (S2), Q41.4 (S2), Q42.4 (S2), Q44.4 (S2), Q45.4 (S2), Q47.4 (S2), Q48.4 (S2), Q50.4 (S2), Q51.4 (S2), Q53.4 (S2), Q54.4 (S2), Q56.4 (S2), Q57.4 (S2), Q59.4 (S2), Q60.4 (S2), Q62.4 (S2), Q63.4 (S2), Q65.4 (S2), Q66.4 (S2), Q68.4 (S2), Q69.4 (S2), Q71.4 (S2), Q72.4 (S2), Q74.4 (S2), Q75.4 (S2), Q77.4 (S2), Q78.4 (S2), Q80.4 (S2), Q81.4 (S2), Q83.4 (S2), Q84.4 (S2), Q86.4 (S2), Q87.4 (S2), Q89.4 (S2), Q90.4 (S2), Q92.4 (S2), Q93.4 (S2), Q95.4 (S2), Q96.4 (S2); also elsewhere on the board

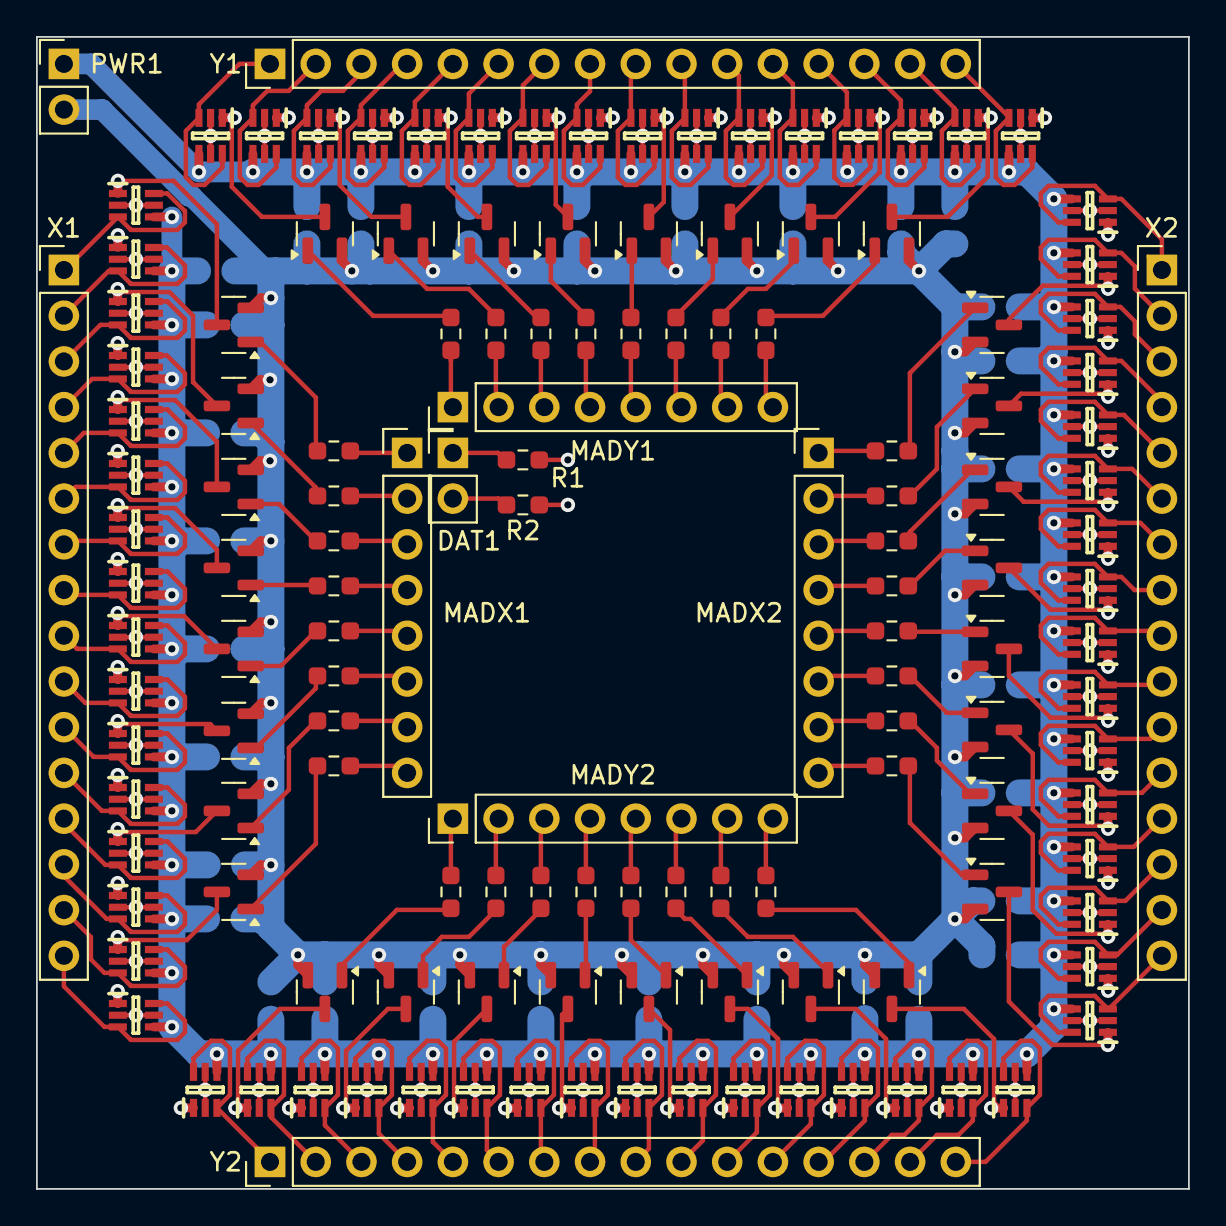
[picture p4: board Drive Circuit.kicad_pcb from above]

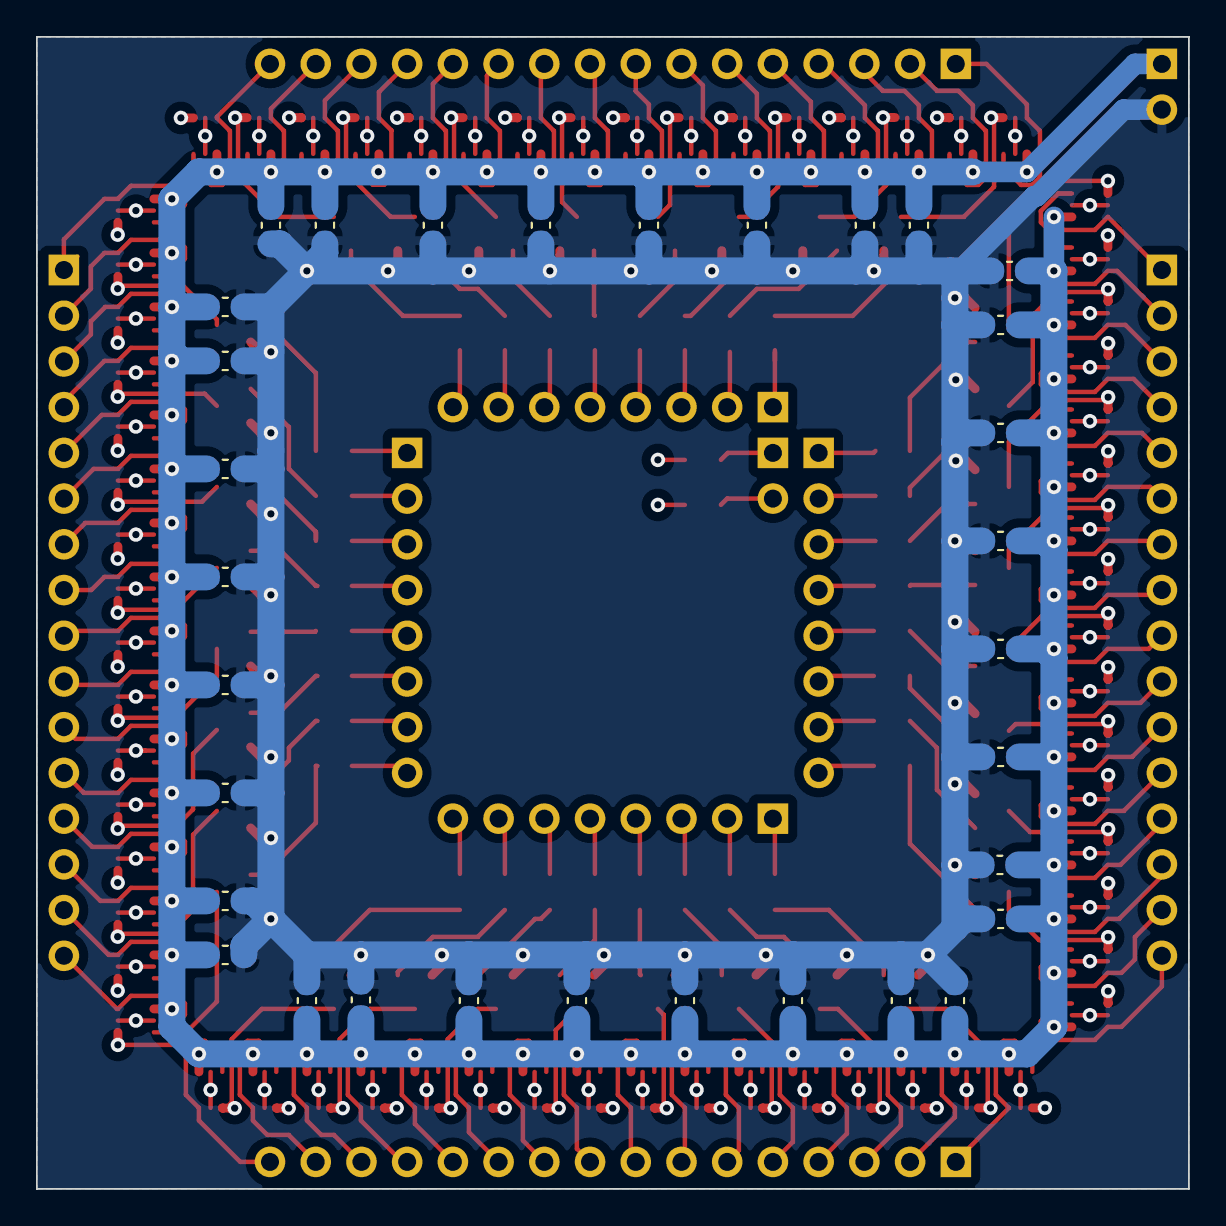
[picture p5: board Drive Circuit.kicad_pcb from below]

Board: 4 copper layers, 64.0 x 64.0 mm, 172 parts (32 on the bottom side), 166 nets.

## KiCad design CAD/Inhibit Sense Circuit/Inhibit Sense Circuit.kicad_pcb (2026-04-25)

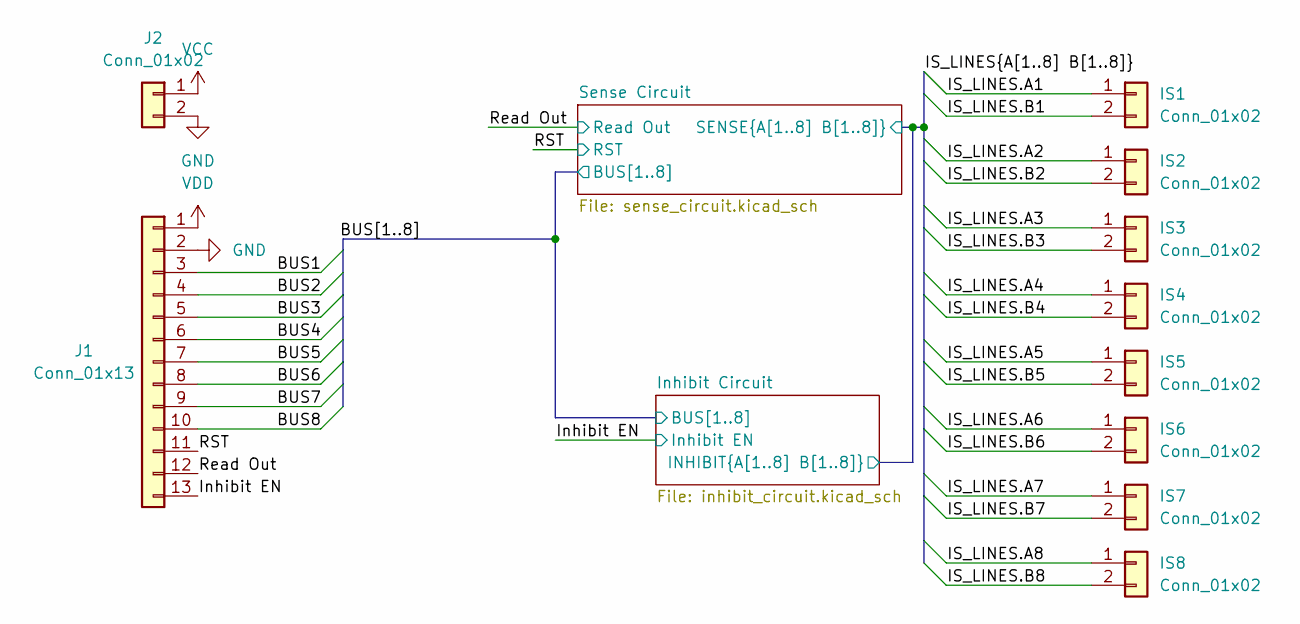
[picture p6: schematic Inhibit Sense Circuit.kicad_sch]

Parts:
IS1, IS2, IS3, IS4, IS5, IS6, IS7, IS8: Conn_01x02; PinHeader_1x02_P2.54mm_Vertical
J1: Conn_01x13; PinHeader_1x13_P2.54mm_Vertical
J2: Conn_01x02; PinHeader_1x02_P2.54mm_Vertical

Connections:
/BUS1: J1.3; also elsewhere on the board
/BUS2: J1.4; also elsewhere on the board
/BUS3: J1.5; also elsewhere on the board
/BUS4: J1.6; also elsewhere on the board
/BUS5: J1.7; also elsewhere on the board
/BUS6: J1.8; also elsewhere on the board
/BUS7: J1.9; also elsewhere on the board
/BUS8: J1.10; also elsewhere on the board
/IS_LINES.A1: IS1.1; also elsewhere on the board
/IS_LINES.A2: IS2.1; also elsewhere on the board
/IS_LINES.A3: IS3.1; also elsewhere on the board
/IS_LINES.A4: IS4.1; also elsewhere on the board
/IS_LINES.A5: IS5.1; also elsewhere on the board
/IS_LINES.A6: IS6.1; also elsewhere on the board
/IS_LINES.A7: IS7.1; also elsewhere on the board
/IS_LINES.A8: IS8.1; also elsewhere on the board
/IS_LINES.B1: IS1.2; also elsewhere on the board
/IS_LINES.B2: IS2.2; also elsewhere on the board
/IS_LINES.B3: IS3.2; also elsewhere on the board
/IS_LINES.B4: IS4.2; also elsewhere on the board
/IS_LINES.B5: IS5.2; also elsewhere on the board
/IS_LINES.B6: IS6.2; also elsewhere on the board
/IS_LINES.B7: IS7.2; also elsewhere on the board
/IS_LINES.B8: IS8.2; also elsewhere on the board
/Inhibit EN: J1.13; also elsewhere on the board
/RST: J1.11; also elsewhere on the board
/Read Out: J1.12; also elsewhere on the board
GND: J1.2, J2.2; also elsewhere on the board
VCC: J2.1; also elsewhere on the board
VDD: J1.1; also elsewhere on the board

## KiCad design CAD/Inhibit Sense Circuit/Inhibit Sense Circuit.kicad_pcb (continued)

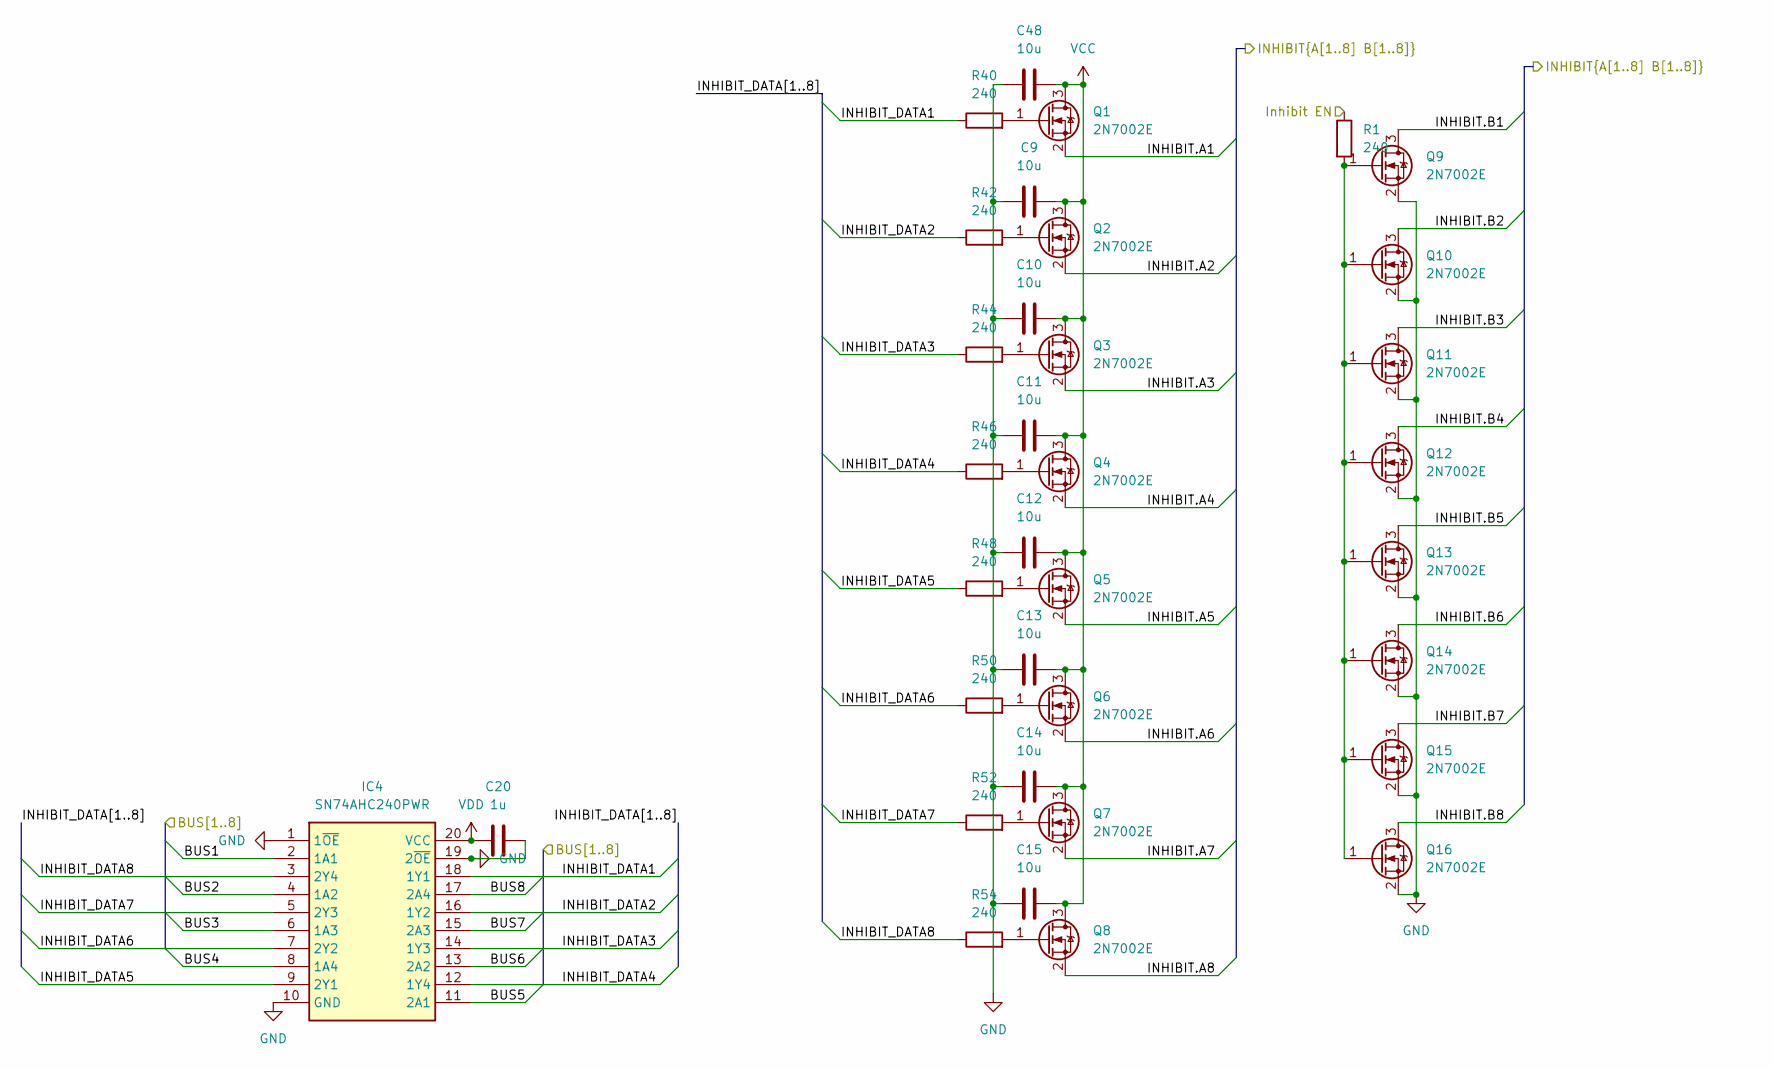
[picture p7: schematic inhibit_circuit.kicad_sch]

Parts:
C9, C10, C11, C12, C13, C14, C15, C48: 10u; C_0603_1608Metric_Pad1.08x0.95mm_HandSolder
C20: 1u; C_0603_1608Metric_Pad1.08x0.95mm_HandSolder
IC4: SN74AHC240PWR; SOP65P640X120-20N; Mouser Part Number 595-SN74AHC240PWR
Q1, Q2, Q3, Q4, Q5, Q6, Q7, Q8, Q9, Q10, Q11, Q12, Q13, Q14, Q15, Q16: 2N7002E; SOT-23
R1, R40, R42, R44, R46, R48, R50, R52, R54: 240; R_0603_1608Metric_Pad0.98x0.95mm_HandSolder

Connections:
/BUS1: IC4.2 (1A1); also elsewhere on the board
/BUS2: IC4.4 (1A2); also elsewhere on the board
/BUS3: IC4.6 (1A3); also elsewhere on the board
/BUS4: IC4.8 (1A4); also elsewhere on the board
/BUS5: IC4.11 (2A1); also elsewhere on the board
/BUS6: IC4.13 (2A2); also elsewhere on the board
/BUS7: IC4.15 (2A3); also elsewhere on the board
/BUS8: IC4.17 (2A4); also elsewhere on the board
/IS_LINES.A1: Q1.2 (S); also elsewhere on the board
/IS_LINES.A2: Q2.2 (S); also elsewhere on the board
/IS_LINES.A3: Q3.2 (S); also elsewhere on the board
/IS_LINES.A4: Q4.2 (S); also elsewhere on the board
/IS_LINES.A5: Q5.2 (S); also elsewhere on the board
/IS_LINES.A6: Q6.2 (S); also elsewhere on the board
/IS_LINES.A7: Q7.2 (S); also elsewhere on the board
/IS_LINES.A8: Q8.2 (S); also elsewhere on the board
/IS_LINES.B1: Q9.3 (D); also elsewhere on the board
/IS_LINES.B2: Q10.3 (D); also elsewhere on the board
/IS_LINES.B3: Q11.3 (D); also elsewhere on the board
/IS_LINES.B4: Q12.3 (D); also elsewhere on the board
/IS_LINES.B5: Q13.3 (D); also elsewhere on the board
/IS_LINES.B6: Q14.3 (D); also elsewhere on the board
/IS_LINES.B7: Q15.3 (D); also elsewhere on the board
/IS_LINES.B8: Q16.3 (D); also elsewhere on the board
/Inhibit Circuit/INHIBIT_DATA1: IC4.18 (1Y1), R40.1
/Inhibit Circuit/INHIBIT_DATA2: IC4.16 (1Y2), R42.1
/Inhibit Circuit/INHIBIT_DATA3: IC4.14 (1Y3), R44.1
/Inhibit Circuit/INHIBIT_DATA4: IC4.12 (1Y4), R46.1
/Inhibit Circuit/INHIBIT_DATA5: IC4.9 (2Y1), R48.1
/Inhibit Circuit/INHIBIT_DATA6: IC4.7 (2Y2), R50.1
/Inhibit Circuit/INHIBIT_DATA7: IC4.5 (2Y3), R52.1
/Inhibit Circuit/INHIBIT_DATA8: IC4.3 (2Y4), R54.1
/Inhibit EN: R1.1; also elsewhere on the board
GND: C9.1, C10.1, C11.1, C12.1, C13.1, C14.1, C15.1, C20.2, C48.1, IC4.1 (1~OE), IC4.10 (GND), IC4.19 (2~OE), Q9.2 (S), Q10.2 (S), Q11.2 (S), Q12.2 (S), Q13.2 (S), Q14.2 (S), Q15.2 (S), Q16.2 (S); also elsewhere on the board
unnamed: Q1.1 (G), R40.2
unnamed: Q2.1 (G), R42.2
unnamed: Q3.1 (G), R44.2
unnamed: Q4.1 (G), R46.2
unnamed: Q5.1 (G), R48.2
unnamed: Q6.1 (G), R50.2
unnamed: Q7.1 (G), R52.2
unnamed: Q8.1 (G), R54.2
unnamed: Q9.1 (G), Q10.1 (G), Q11.1 (G), Q12.1 (G), Q13.1 (G), Q14.1 (G), Q15.1 (G), Q16.1 (G), R1.2
VCC: C9.2, C10.2, C11.2, C12.2, C13.2, C14.2, C15.2, C48.2, Q1.3 (D), Q2.3 (D), Q3.3 (D), Q4.3 (D), Q5.3 (D), Q6.3 (D), Q7.3 (D), Q8.3 (D); also elsewhere on the board
VDD: C20.1, IC4.20 (VCC); also elsewhere on the board

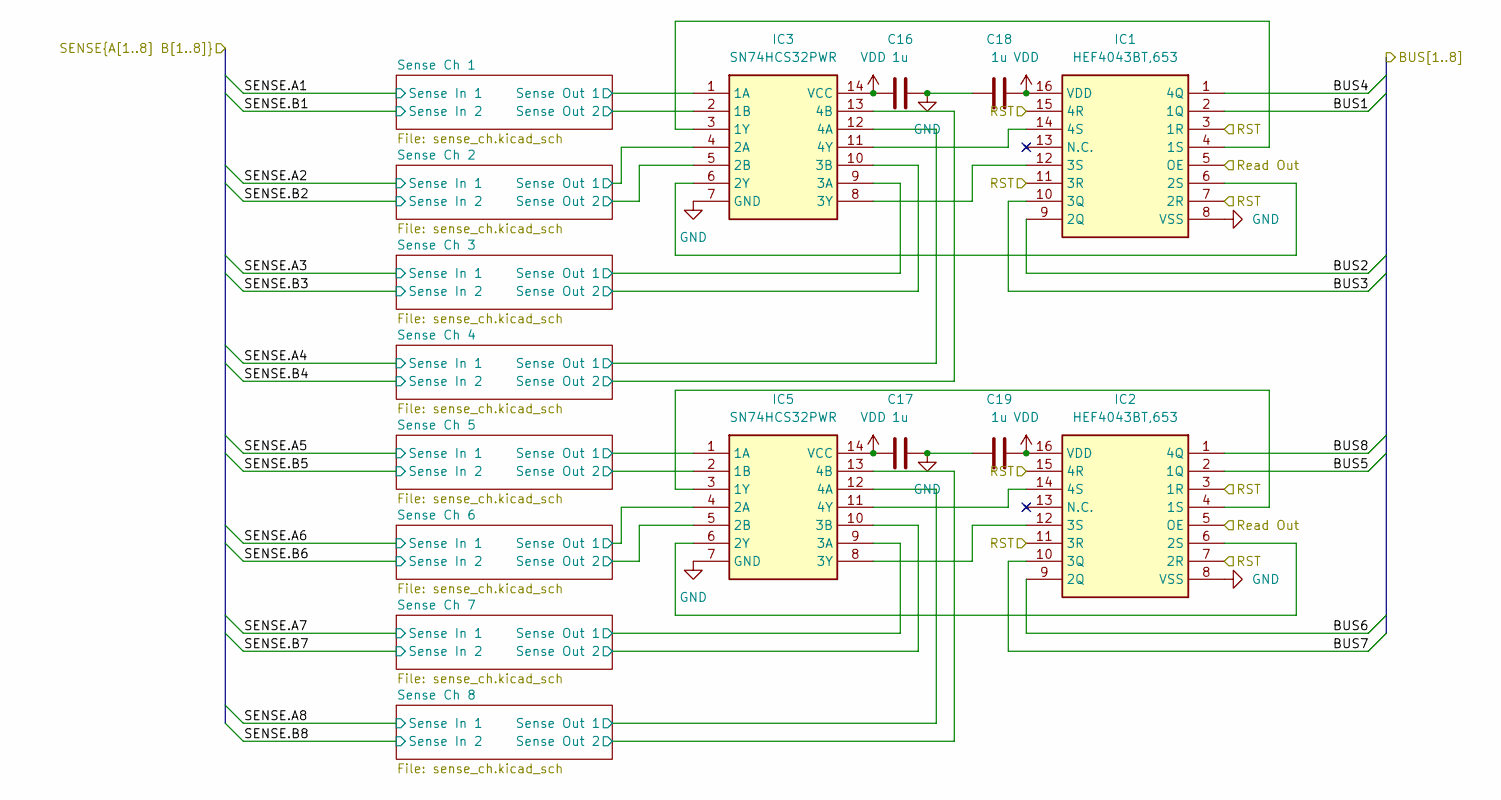
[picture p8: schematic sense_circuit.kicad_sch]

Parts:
C16, C17, C18, C19: 1u; C_0603_1608Metric_Pad1.08x0.95mm_HandSolder
IC1, IC2: HEF4043BT,653; HEF4043BT653; Mouser Part Number 771-HEF4043BT653
IC3, IC5: SN74HCS32PWR; SOP65P640X120-14N; Mouser Part Number 595-SN74HCS32PWR

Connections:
/BUS1: IC1.2 (1Q); also elsewhere on the board
/BUS2: IC1.9 (2Q); also elsewhere on the board
/BUS3: IC1.10 (3Q); also elsewhere on the board
/BUS4: IC1.1 (4Q); also elsewhere on the board
/BUS5: IC2.2 (1Q); also elsewhere on the board
/BUS6: IC2.9 (2Q); also elsewhere on the board
/BUS7: IC2.10 (3Q); also elsewhere on the board
/BUS8: IC2.1 (4Q); also elsewhere on the board
/RST: IC1.3 (1R), IC1.7 (2R), IC1.11 (3R), IC1.15 (4R), IC2.3 (1R), IC2.7 (2R), IC2.11 (3R), IC2.15 (4R); also elsewhere on the board
/Read Out: IC1.5 (OE), IC2.5 (OE); also elsewhere on the board
/Sense Circuit/Sense Ch 1/Sense Out 1: IC3.1 (1A); also elsewhere on the board
/Sense Circuit/Sense Ch 1/Sense Out 2: IC3.2 (1B); also elsewhere on the board
/Sense Circuit/Sense Ch 2/Sense Out 1: IC3.4 (2A); also elsewhere on the board
/Sense Circuit/Sense Ch 2/Sense Out 2: IC3.5 (2B); also elsewhere on the board
/Sense Circuit/Sense Ch 3/Sense Out 1: IC3.9 (3A); also elsewhere on the board
/Sense Circuit/Sense Ch 3/Sense Out 2: IC3.10 (3B); also elsewhere on the board
/Sense Circuit/Sense Ch 4/Sense Out 1: IC3.12 (4A); also elsewhere on the board
/Sense Circuit/Sense Ch 4/Sense Out 2: IC3.13 (4B); also elsewhere on the board
/Sense Circuit/Sense Ch 5/Sense Out 1: IC5.1 (1A); also elsewhere on the board
/Sense Circuit/Sense Ch 5/Sense Out 2: IC5.2 (1B); also elsewhere on the board
/Sense Circuit/Sense Ch 6/Sense Out 1: IC5.4 (2A); also elsewhere on the board
/Sense Circuit/Sense Ch 6/Sense Out 2: IC5.5 (2B); also elsewhere on the board
/Sense Circuit/Sense Ch 7/Sense Out 1: IC5.9 (3A); also elsewhere on the board
/Sense Circuit/Sense Ch 7/Sense Out 2: IC5.10 (3B); also elsewhere on the board
/Sense Circuit/Sense Ch 8/Sense Out 1: IC5.12 (4A); also elsewhere on the board
/Sense Circuit/Sense Ch 8/Sense Out 2: IC5.13 (4B); also elsewhere on the board
GND: C16.2, C17.2, C18.1, C19.1, IC1.8 (VSS), IC2.8 (VSS), IC3.7 (GND), IC5.7 (GND); also elsewhere on the board
unnamed: IC1.4 (1S), IC3.3 (1Y)
unnamed: IC1.6 (2S), IC3.6 (2Y)
unnamed: IC1.12 (3S), IC3.8 (3Y)
unnamed: IC1.14 (4S), IC3.11 (4Y)
unnamed: IC2.4 (1S), IC5.3 (1Y)
unnamed: IC2.6 (2S), IC5.6 (2Y)
unnamed: IC2.12 (3S), IC5.8 (3Y)
unnamed: IC2.14 (4S), IC5.11 (4Y)
VDD: C16.1, C17.1, C18.2, C19.2, IC1.16 (VDD), IC2.16 (VDD), IC3.14 (VCC), IC5.14 (VCC); also elsewhere on the board

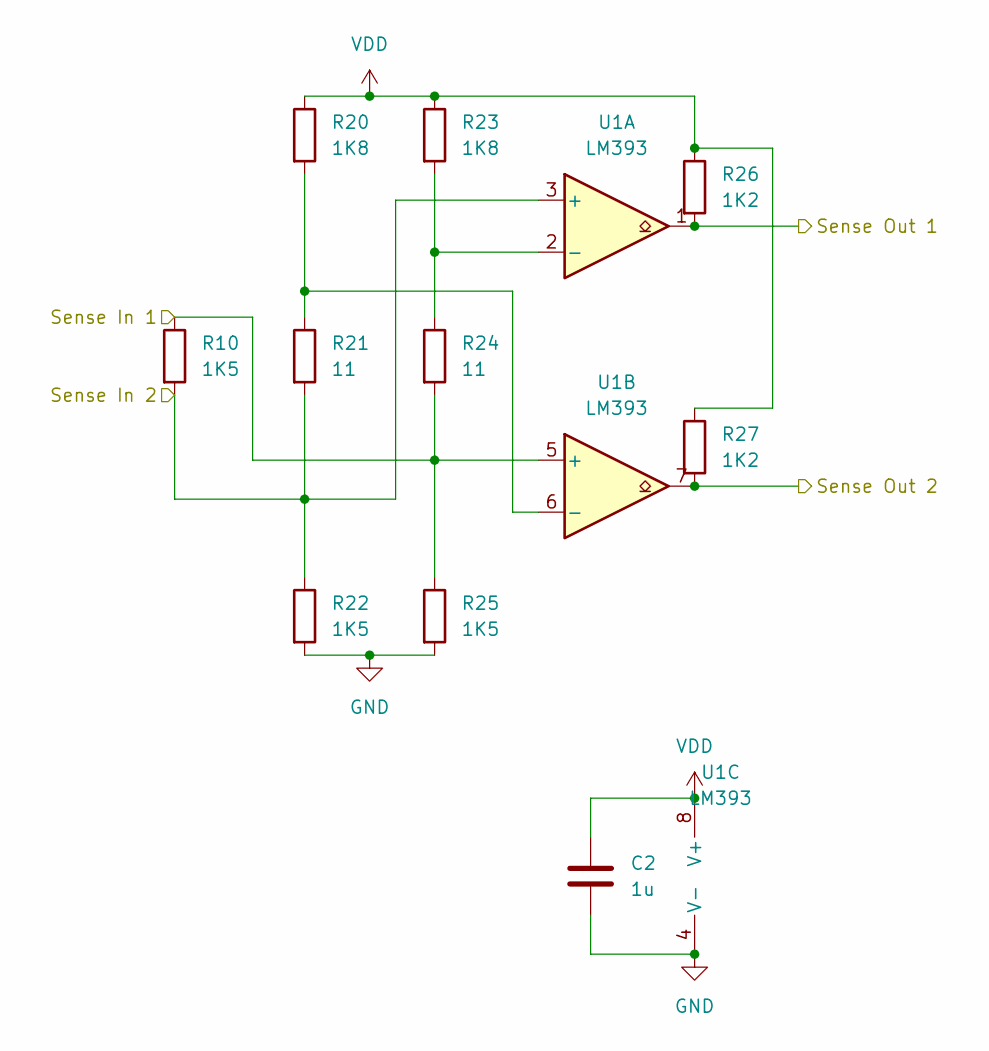
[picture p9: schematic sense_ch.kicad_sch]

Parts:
C2: 1u; C_0603_1608Metric_Pad1.08x0.95mm_HandSolder
R10, R22, R25: 1K5; R_0603_1608Metric_Pad0.98x0.95mm_HandSolder
R20, R23: 1K8; R_0603_1608Metric_Pad0.98x0.95mm_HandSolder
R21, R24: 11; R_0603_1608Metric_Pad0.98x0.95mm_HandSolder
R26, R27: 1K2; R_0603_1608Metric_Pad0.98x0.95mm_HandSolder
U1: LM393; SO1SOP-8-A_TPK

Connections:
/IS_LINES.A1: R10.1, R24.2, R25.1, U1.5 (+); also elsewhere on the board
/IS_LINES.B1: R10.2, R21.2, R22.1, U1.3 (+); also elsewhere on the board
/Sense Circuit/Sense Ch 1/Sense Out 1: R26.2, U1.1; also elsewhere on the board
/Sense Circuit/Sense Ch 1/Sense Out 2: R27.2, U1.7; also elsewhere on the board
GND: C2.2, R22.2, R25.2, U1.4 (V-); also elsewhere on the board
unnamed: R23.2, R24.1, U1.2 (-)
unnamed: R20.2, R21.1, U1.6 (-)
VDD: C2.1, R20.1, R23.1, R26.1, R27.1, U1.8 (V+); also elsewhere on the board

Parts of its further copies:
C1, C3, C4, C5, C6, C7, C8: 1u; C_0603_1608Metric_Pad1.08x0.95mm_HandSolder
R9, R13, R16, R19, R28, R31, R34, R37, R41, R47, R53, R57, R60, R63, R66, R69, R72, R75, R78, R83, R86: 1K5; R_0603_1608Metric_Pad0.98x0.95mm_HandSolder
R11, R14, R29, R32, R38, R43, R55, R58, R64, R67, R73, R76, R81, R84: 1K8; R_0603_1608Metric_Pad0.98x0.95mm_HandSolder
R12, R15, R30, R33, R39, R45, R56, R59, R65, R68, R74, R77, R82, R85: 11; R_0603_1608Metric_Pad0.98x0.95mm_HandSolder
R17, R18, R35, R36, R49, R51, R61, R62, R70, R71, R79, R80, R87, R88: 1K2; R_0603_1608Metric_Pad0.98x0.95mm_HandSolder
U2, U3, U4, U5, U6, U7, U8: LM393; SO1SOP-8-A_TPK

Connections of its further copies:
/IS_LINES.A2: R9.1, R15.2, R16.1, U2.5 (+); also elsewhere on the board
/IS_LINES.A3: R19.1, R33.2, R34.1, U3.5 (+); also elsewhere on the board
/IS_LINES.A4: R28.1, R45.2, R47.1, U4.5 (+); also elsewhere on the board
/IS_LINES.A5: R37.1, R59.2, R60.1, U5.5 (+); also elsewhere on the board
/IS_LINES.A6: R53.1, R68.2, R69.1, U6.5 (+); also elsewhere on the board
/IS_LINES.A7: R63.1, R77.2, R78.1, U7.5 (+); also elsewhere on the board
/IS_LINES.A8: R72.1, R85.2, R86.1, U8.5 (+); also elsewhere on the board
/IS_LINES.B2: R9.2, R12.2, R13.1, U2.3 (+); also elsewhere on the board
/IS_LINES.B3: R19.2, R30.2, R31.1, U3.3 (+); also elsewhere on the board
/IS_LINES.B4: R28.2, R39.2, R41.1, U4.3 (+); also elsewhere on the board
/IS_LINES.B5: R37.2, R56.2, R57.1, U5.3 (+); also elsewhere on the board
/IS_LINES.B6: R53.2, R65.2, R66.1, U6.3 (+); also elsewhere on the board
/IS_LINES.B7: R63.2, R74.2, R75.1, U7.3 (+); also elsewhere on the board
/IS_LINES.B8: R72.2, R82.2, R83.1, U8.3 (+); also elsewhere on the board
/Sense Circuit/Sense Ch 2/Sense Out 1: R17.2, U2.1; also elsewhere on the board
/Sense Circuit/Sense Ch 2/Sense Out 2: R18.2, U2.7; also elsewhere on the board
/Sense Circuit/Sense Ch 3/Sense Out 1: R35.2, U3.1; also elsewhere on the board
/Sense Circuit/Sense Ch 3/Sense Out 2: R36.2, U3.7; also elsewhere on the board
/Sense Circuit/Sense Ch 4/Sense Out 1: R49.2, U4.1; also elsewhere on the board
/Sense Circuit/Sense Ch 4/Sense Out 2: R51.2, U4.7; also elsewhere on the board
/Sense Circuit/Sense Ch 5/Sense Out 1: R61.2, U5.1; also elsewhere on the board
/Sense Circuit/Sense Ch 5/Sense Out 2: R62.2, U5.7; also elsewhere on the board
/Sense Circuit/Sense Ch 6/Sense Out 1: R70.2, U6.1; also elsewhere on the board
/Sense Circuit/Sense Ch 6/Sense Out 2: R71.2, U6.7; also elsewhere on the board
/Sense Circuit/Sense Ch 7/Sense Out 1: R79.2, U7.1; also elsewhere on the board
/Sense Circuit/Sense Ch 7/Sense Out 2: R80.2, U7.7; also elsewhere on the board
/Sense Circuit/Sense Ch 8/Sense Out 1: R87.2, U8.1; also elsewhere on the board
/Sense Circuit/Sense Ch 8/Sense Out 2: R88.2, U8.7; also elsewhere on the board
GND: C1.2, C3.2, C4.2, C5.2, C6.2, C7.2, C8.2, R13.2, R16.2, R31.2, R34.2, R41.2, R47.2, R57.2, R60.2, R66.2, R69.2, R75.2, R78.2, R83.2, R86.2, U2.4 (V-), U3.4 (V-), U4.4 (V-), U5.4 (V-), U6.4 (V-), U7.4 (V-), U8.4 (V-); also elsewhere on the board
unnamed: R14.2, R15.1, U2.2 (-)
unnamed: R11.2, R12.1, U2.6 (-)
unnamed: R32.2, R33.1, U3.2 (-)
unnamed: R29.2, R30.1, U3.6 (-)
unnamed: R43.2, R45.1, U4.2 (-)
unnamed: R38.2, R39.1, U4.6 (-)
unnamed: R58.2, R59.1, U5.2 (-)
unnamed: R55.2, R56.1, U5.6 (-)
unnamed: R67.2, R68.1, U6.2 (-)
unnamed: R64.2, R65.1, U6.6 (-)
unnamed: R76.2, R77.1, U7.2 (-)
unnamed: R73.2, R74.1, U7.6 (-)
unnamed: R84.2, R85.1, U8.2 (-)
unnamed: R81.2, R82.1, U8.6 (-)
VDD: C1.1, C3.1, C4.1, C5.1, C6.1, C7.1, C8.1, R11.1, R14.1, R17.1, R18.1, R29.1, R32.1, R35.1, R36.1, R38.1, R43.1, R49.1, R51.1, R55.1, R58.1, R61.1, R62.1, R64.1, R67.1, R70.1, R71.1, R73.1, R76.1, R79.1, R80.1, R81.1, R84.1, R87.1, R88.1, U2.8 (V+), U3.8 (V+), U4.8 (V+), U5.8 (V+), U6.8 (V+), U7.8 (V+), U8.8 (V+); also elsewhere on the board

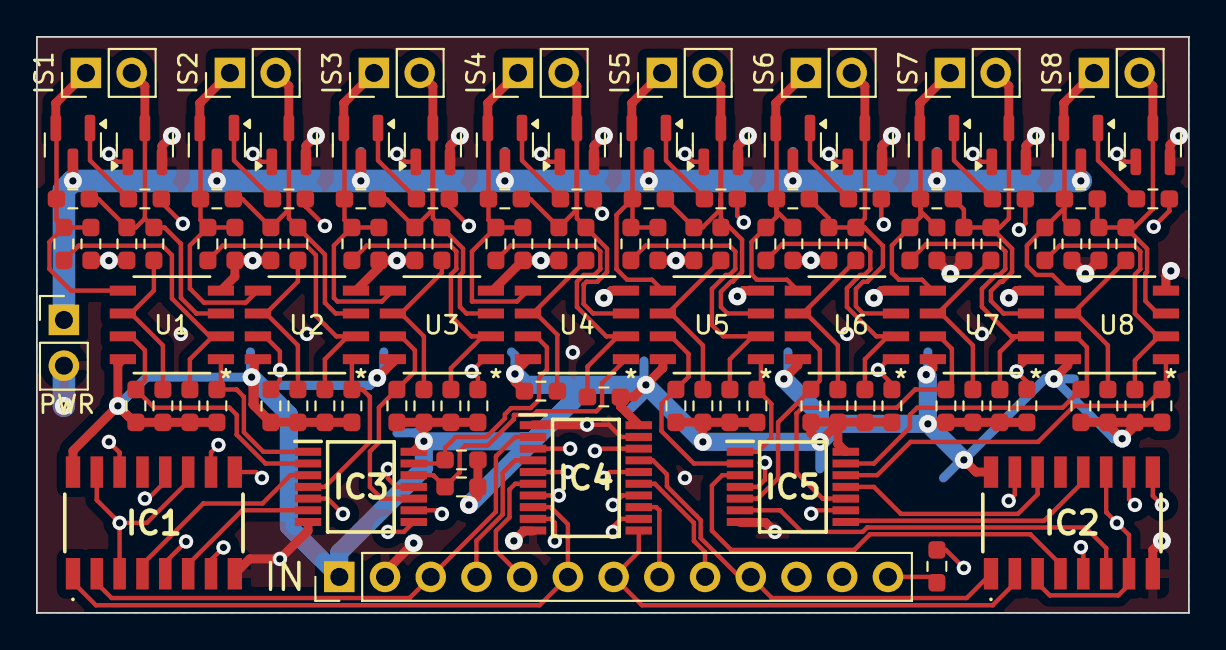
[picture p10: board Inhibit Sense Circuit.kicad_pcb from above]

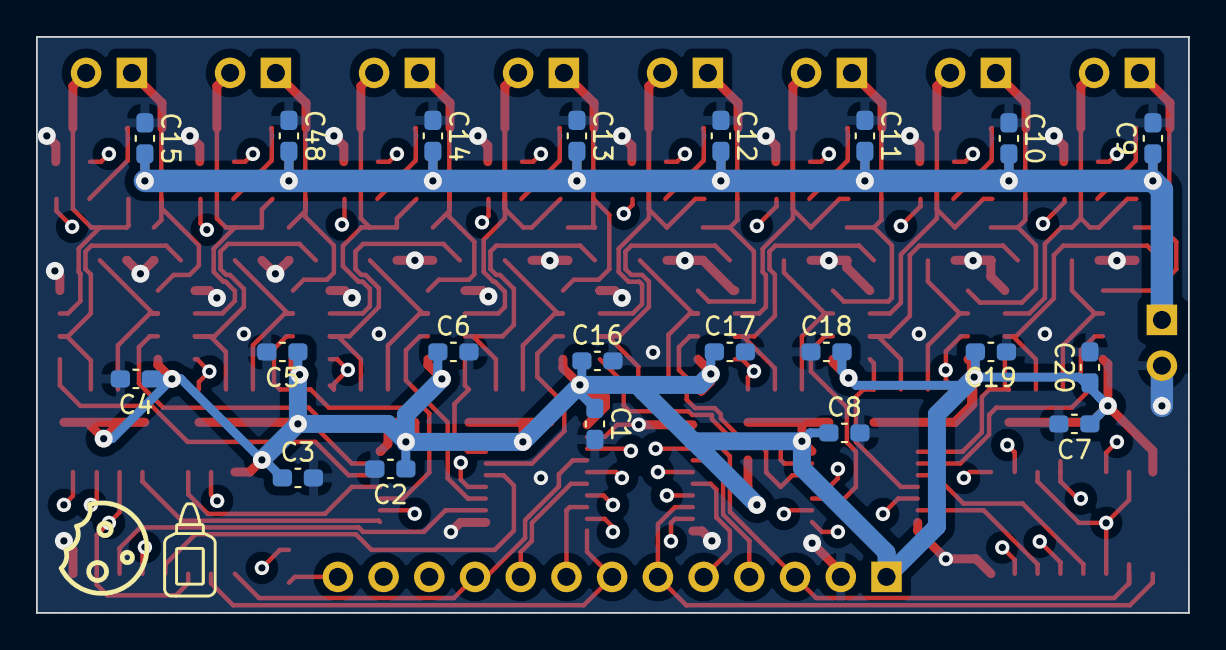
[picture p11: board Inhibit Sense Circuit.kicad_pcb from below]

Board: 4 copper layers, 64.0 x 32.0 mm, 141 parts (21 on the bottom side), 87 nets.

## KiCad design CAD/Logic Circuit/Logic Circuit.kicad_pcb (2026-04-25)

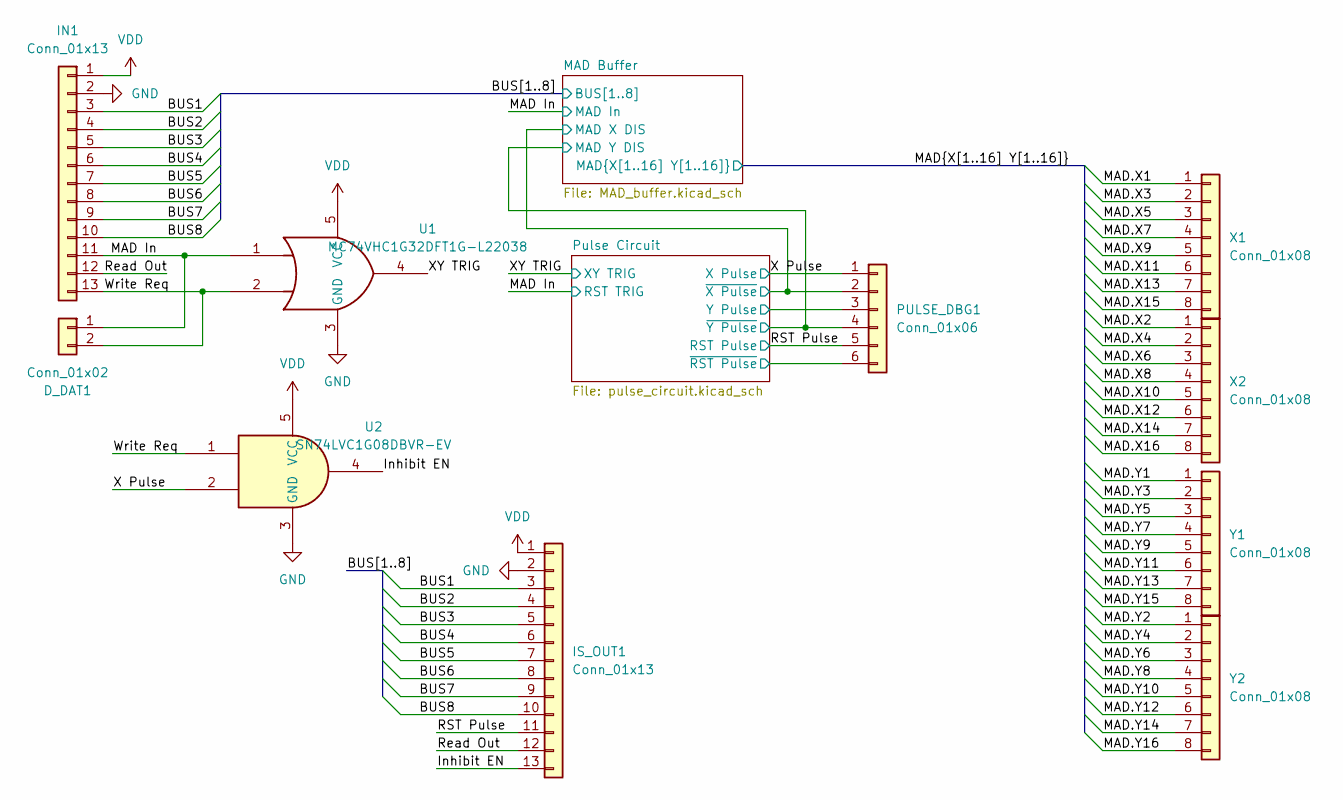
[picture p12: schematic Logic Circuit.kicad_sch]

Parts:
D_DAT1: Conn_01x02; PinSocket_1x02_P2.54mm_Vertical
IN1: Conn_01x13; PinHeader_1x13_P2.54mm_Vertical
IS_OUT1: Conn_01x13; PinHeader_1x13_P2.54mm_Vertical
PULSE_DBG1: Conn_01x06; PinSocket_1x06_P2.54mm_Vertical
U1: MC74VHC1G32DFT1G-L22038; SOT-353_SC-70-5_Handsoldering
U2: SN74LVC1G08DBVR-EV; SOT-23-5_HandSoldering
X1, X2: Conn_01x08; PinHeader_1x08_P2.54mm_Vertical
Y1, Y2: Conn_01x08; PinHeader_1x08_P2.54mm_Vertical

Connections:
/BUS1: IN1.3, IS_OUT1.3; also elsewhere on the board
/BUS2: IN1.4, IS_OUT1.4; also elsewhere on the board
/BUS3: IN1.5, IS_OUT1.5; also elsewhere on the board
/BUS4: IN1.6, IS_OUT1.6; also elsewhere on the board
/BUS5: IN1.7, IS_OUT1.7; also elsewhere on the board
/BUS6: IN1.8, IS_OUT1.8; also elsewhere on the board
/BUS7: IN1.9, IS_OUT1.9; also elsewhere on the board
/BUS8: IN1.10, IS_OUT1.10; also elsewhere on the board
/Inhibit EN: IS_OUT1.13, U2.4
/MAD Buffer/MAD X DIS: PULSE_DBG1.2; also elsewhere on the board
/MAD Buffer/MAD Y DIS: PULSE_DBG1.4; also elsewhere on the board
/MAD In: D_DAT1.1, IN1.11, U1.1; also elsewhere on the board
/MAD.X1: X1.1; also elsewhere on the board
/MAD.X2: X2.1; also elsewhere on the board
/MAD.X3: X1.2; also elsewhere on the board
/MAD.X4: X2.2; also elsewhere on the board
/MAD.X5: X1.3; also elsewhere on the board
/MAD.X6: X2.3; also elsewhere on the board
/MAD.X7: X1.4; also elsewhere on the board
/MAD.X8: X2.4; also elsewhere on the board
/MAD.X9: X1.5; also elsewhere on the board
/MAD.X10: X2.5; also elsewhere on the board
/MAD.X11: X1.6; also elsewhere on the board
/MAD.X12: X2.6; also elsewhere on the board
/MAD.X13: X1.7; also elsewhere on the board
/MAD.X14: X2.7; also elsewhere on the board
/MAD.X15: X1.8; also elsewhere on the board
/MAD.X16: X2.8; also elsewhere on the board
/MAD.Y1: Y1.1; also elsewhere on the board
/MAD.Y2: Y2.1; also elsewhere on the board
/MAD.Y3: Y1.2; also elsewhere on the board
/MAD.Y4: Y2.2; also elsewhere on the board
/MAD.Y5: Y1.3; also elsewhere on the board
/MAD.Y6: Y2.3; also elsewhere on the board
/MAD.Y7: Y1.4; also elsewhere on the board
/MAD.Y8: Y2.4; also elsewhere on the board
/MAD.Y9: Y1.5; also elsewhere on the board
/MAD.Y10: Y2.5; also elsewhere on the board
/MAD.Y11: Y1.6; also elsewhere on the board
/MAD.Y12: Y2.6; also elsewhere on the board
/MAD.Y13: Y1.7; also elsewhere on the board
/MAD.Y14: Y2.7; also elsewhere on the board
/MAD.Y15: Y1.8; also elsewhere on the board
/MAD.Y16: Y2.8; also elsewhere on the board
/Pulse Circuit/Y Pulse: PULSE_DBG1.3; also elsewhere on the board
/Pulse Circuit/~RST Pulse: PULSE_DBG1.6; also elsewhere on the board
/RST Pulse: IS_OUT1.11, PULSE_DBG1.5; also elsewhere on the board
/Read Out: IN1.12, IS_OUT1.12
/Write Req: D_DAT1.2, IN1.13, U1.2, U2.1
/X Pulse: PULSE_DBG1.1, U2.2; also elsewhere on the board
/XY TRIG: U1.4; also elsewhere on the board
GND: IN1.2, IS_OUT1.2, U1.3 (GND), U2.3 (GND); also elsewhere on the board
VDD: IN1.1, IS_OUT1.1, U1.5 (VCC), U2.5 (VCC); also elsewhere on the board


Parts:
C6, C7: 1u; C_0603_1608Metric_Pad1.08x0.95mm_HandSolder
IC1, IC3: 74HC4514PW,118; SOP65P640X110-24N; Mouser Part Number 771-HC4514PW118
R1, R2, R3, R4, R6, R8, R11, R14, R15, R16, R17, R18, R21, R22, R23, R24, R25, R26, R27, R28, R29, R30, R31, R32, R33, R34, R35, R36, R37, R38, R40, R41: 10k; R_0603_1608Metric_Pad0.98x0.95mm_HandSolder

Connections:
/BUS1: IC3.2 (A0); also elsewhere on the board
/BUS2: IC3.3 (A1); also elsewhere on the board
/BUS3: IC3.21 (A2); also elsewhere on the board
/BUS4: IC3.22 (A3); also elsewhere on the board
/BUS5: IC1.2 (A0); also elsewhere on the board
/BUS6: IC1.3 (A1); also elsewhere on the board
/BUS7: IC1.21 (A2); also elsewhere on the board
/BUS8: IC1.22 (A3); also elsewhere on the board
/MAD Buffer/MAD X DIS: IC3.23 (~E); also elsewhere on the board
/MAD Buffer/MAD Y DIS: IC1.23 (~E); also elsewhere on the board
/MAD In: IC1.1 (LE), IC3.1 (LE); also elsewhere on the board
/MAD.X1: IC3.11 (Q0), R3.2; also elsewhere on the board
/MAD.X2: IC3.9 (Q1), R17.2; also elsewhere on the board
/MAD.X3: IC3.10 (Q2), R2.2; also elsewhere on the board
/MAD.X4: IC3.8 (Q3), R14.2; also elsewhere on the board
/MAD.X5: IC3.7 (Q4), R21.2; also elsewhere on the board
/MAD.X6: IC3.6 (Q5), R30.2; also elsewhere on the board
/MAD.X7: IC3.5 (Q6), R23.2; also elsewhere on the board
/MAD.X8: IC3.4 (Q7), R40.2; also elsewhere on the board
/MAD.X9: IC3.18 (Q8), R25.2; also elsewhere on the board
/MAD.X10: IC3.17 (Q9), R35.2; also elsewhere on the board
/MAD.X11: IC3.20 (Q10), R22.2; also elsewhere on the board
/MAD.X12: IC3.19 (Q11), R31.2; also elsewhere on the board
/MAD.X13: IC3.14 (Q12), R27.2; also elsewhere on the board
/MAD.X14: IC3.13 (Q13), R34.2; also elsewhere on the board
/MAD.X15: IC3.16 (Q14), R26.2; also elsewhere on the board
/MAD.X16: IC3.15 (Q15), R36.2; also elsewhere on the board
/MAD.Y1: IC1.11 (Q0), R4.2; also elsewhere on the board
/MAD.Y2: IC1.9 (Q1), R24.2; also elsewhere on the board
/MAD.Y3: IC1.10 (Q2), R1.2; also elsewhere on the board
/MAD.Y4: IC1.8 (Q3), R28.2; also elsewhere on the board
/MAD.Y5: IC1.7 (Q4), R15.2; also elsewhere on the board
/MAD.Y6: IC1.6 (Q5), R32.2; also elsewhere on the board
/MAD.Y7: IC1.5 (Q6), R8.2; also elsewhere on the board
/MAD.Y8: IC1.4 (Q7), R37.2; also elsewhere on the board
/MAD.Y9: IC1.18 (Q8), R11.2; also elsewhere on the board
/MAD.Y10: IC1.17 (Q9), R29.2; also elsewhere on the board
/MAD.Y11: IC1.20 (Q10), R16.2; also elsewhere on the board
/MAD.Y12: IC1.19 (Q11), R41.2; also elsewhere on the board
/MAD.Y13: IC1.14 (Q12), R18.2; also elsewhere on the board
/MAD.Y14: IC1.13 (Q13), R33.2; also elsewhere on the board
/MAD.Y15: IC1.16 (Q14), R6.2; also elsewhere on the board
/MAD.Y16: IC1.15 (Q15), R38.2; also elsewhere on the board
GND: C6.1, C7.1, IC1.12 (GND), IC3.12 (GND), R1.1, R2.1, R3.1, R4.1, R6.1, R8.1, R11.1, R14.1, R15.1, R16.1, R17.1, R18.1, R21.1, R22.1, R23.1, R24.1, R25.1, R26.1, R27.1, R28.1, R29.1, R30.1, R31.1, R32.1, R33.1, R34.1, R35.1, R36.1, R37.1, R38.1, R40.1, R41.1; also elsewhere on the board
VDD: C6.2, C7.2, IC1.24 (VCC), IC3.24 (VCC); also elsewhere on the board


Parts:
C1, C2: 1000p; C_0603_1608Metric_Pad1.08x0.95mm_HandSolder
C3, C4: 220p; C_0603_1608Metric_Pad1.08x0.95mm_HandSolder
C8, C9: 1u; C_0603_1608Metric_Pad1.08x0.95mm_HandSolder
IC4, IC5: 74AHC123AD,118; SOIC127P600X175-16N; Mouser Part Number 771-AHC123AD118
R39, R44: 1k; R_0603_1608Metric_Pad0.98x0.95mm_HandSolder
R42, R43: 5.1k; R_0603_1608Metric_Pad0.98x0.95mm_HandSolder
RV1, RV2, RV3: R_Potentiometer; Potentiometer_Bourns_3296W_Vertical

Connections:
/MAD Buffer/MAD X DIS: IC4.4 (1~Q); also elsewhere on the board
/MAD Buffer/MAD Y DIS: IC4.12 (2~Q); also elsewhere on the board
/MAD In: IC5.2 (1B); also elsewhere on the board
/Pulse Circuit/Y Pulse: IC4.5 (2Q); also elsewhere on the board
/Pulse Circuit/Y Trig: C3.1, IC4.10 (2B), RV1.2
/Pulse Circuit/~RST Pulse: IC5.4 (1~Q); also elsewhere on the board
/RST Pulse: IC5.13 (1Q); also elsewhere on the board
/X Pulse: IC4.13 (1Q); also elsewhere on the board
/XY TRIG: IC4.2 (1B), R44.1; also elsewhere on the board
GND: C1.2, C2.1, C3.2, C4.1, C8.1, C9.1, IC4.6 (2CEXT), IC4.8 (GND), IC4.14 (1CEXT), IC5.8 (GND), IC5.14 (1CEXT); also elsewhere on the board
unnamed: C2.2, IC4.15 (1REXT/CEXT), R42.1
unnamed: C1.1, IC4.7 (2REXT/CEXT), R43.2
unnamed: C4.2, IC5.15 (1REXT/CEXT), R39.1
unnamed: R42.2, RV2.1
unnamed: R43.1, RV3.1
unnamed: R44.2, RV1.1
VDD: C8.2, C9.2, IC4.1 (1~A), IC4.3 (1~RD), IC4.9 (2~A), IC4.11 (2~RD), IC4.16 (VCC), IC5.1 (1~A), IC5.3 (1~RD), IC5.16 (VCC), R39.2, RV2.2, RV3.2; also elsewhere on the board


Board: 4 copper layers, 64.0 x 64.0 mm, 61 parts (0 on the bottom side), 60 nets.

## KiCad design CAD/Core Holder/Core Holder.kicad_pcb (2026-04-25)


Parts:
R1, R2, R3, R4, R5, R6, R7, R8, R9, R10, R11, R12, R13, R14, R15, R16, R17, R18, R19, R20, R21, R22, R23, R24, R25, R26, R27, R28, R29, R30, R31, R32: 10; R_0603_1608Metric_Pad0.98x0.95mm_HandSolder
X1, X1.1, X1.2, X2, X2.1, X2.2: Conn_01x16; PinHeader_1x16_P2.54mm_Vertical
Y1, Y1.1, Y1.2, Y2, Y2.1, Y2.2: Conn_01x16; PinHeader_1x16_P2.54mm_Vertical

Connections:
unnamed: R1.2, X1.1
unnamed: X1.2, X1.1.2, X1.2.2
unnamed: R2.2, X1.3
unnamed: X1.4, X1.1.4, X1.2.4
unnamed: R3.2, X1.5
unnamed: X1.6, X1.1.6, X1.2.6
unnamed: R4.2, X1.7
unnamed: X1.8, X1.1.8, X1.2.8
unnamed: R5.2, X1.9
unnamed: X1.10, X1.1.10, X1.2.10
unnamed: R6.2, X1.11
unnamed: X1.12, X1.1.12, X1.2.12
unnamed: R7.2, X1.13
unnamed: X1.14, X1.1.14, X1.2.14
unnamed: R8.2, X1.15
unnamed: X1.16, X1.1.16, X1.2.16
unnamed: R1.1, X1.1.1, X1.2.1
unnamed: R2.1, X1.1.3, X1.2.3
unnamed: R3.1, X1.1.5, X1.2.5
unnamed: R4.1, X1.1.7, X1.2.7
unnamed: R5.1, X1.1.9, X1.2.9
unnamed: R6.1, X1.1.11, X1.2.11
unnamed: R7.1, X1.1.13, X1.2.13
unnamed: R8.1, X1.1.15, X1.2.15
unnamed: X2.1, X2.1.1, X2.2.1
unnamed: R9.2, X2.2
unnamed: X2.3, X2.1.3, X2.2.3
unnamed: R10.2, X2.4
unnamed: X2.5, X2.1.5, X2.2.5
unnamed: R11.2, X2.6
unnamed: X2.7, X2.1.7, X2.2.7
unnamed: R12.2, X2.8
unnamed: X2.9, X2.1.9, X2.2.9
unnamed: R13.2, X2.10
unnamed: X2.11, X2.1.11, X2.2.11
unnamed: R14.2, X2.12
unnamed: X2.13, X2.1.13, X2.2.13
unnamed: R15.2, X2.14
unnamed: X2.15, X2.1.15, X2.2.15
unnamed: R16.2, X2.16
unnamed: R9.1, X2.1.2, X2.2.2
unnamed: R10.1, X2.1.4, X2.2.4
unnamed: R11.1, X2.1.6, X2.2.6
unnamed: R12.1, X2.1.8, X2.2.8
unnamed: R13.1, X2.1.10, X2.2.10
unnamed: R14.1, X2.1.12, X2.2.12
unnamed: R15.1, X2.1.14, X2.2.14
unnamed: R16.1, X2.1.16, X2.2.16
unnamed: R17.2, Y1.1
unnamed: Y1.2, Y1.1.2, Y1.2.2
unnamed: R18.2, Y1.3
unnamed: Y1.4, Y1.1.4, Y1.2.4
unnamed: R19.2, Y1.5
unnamed: Y1.6, Y1.1.6, Y1.2.6
unnamed: R20.2, Y1.7
unnamed: Y1.8, Y1.1.8, Y1.2.8
unnamed: R21.2, Y1.9
unnamed: Y1.10, Y1.1.10, Y1.2.10
unnamed: R22.2, Y1.11
unnamed: Y1.12, Y1.1.12, Y1.2.12
unnamed: R23.2, Y1.13
unnamed: Y1.14, Y1.1.14, Y1.2.14
unnamed: R24.2, Y1.15
unnamed: Y1.16, Y1.1.16, Y1.2.16
unnamed: R17.1, Y1.1.1, Y1.2.1
unnamed: R18.1, Y1.1.3, Y1.2.3
unnamed: R19.1, Y1.1.5, Y1.2.5
unnamed: R20.1, Y1.1.7, Y1.2.7
unnamed: R21.1, Y1.1.9, Y1.2.9
unnamed: R22.1, Y1.1.11, Y1.2.11
unnamed: R23.1, Y1.1.13, Y1.2.13
unnamed: R24.1, Y1.1.15, Y1.2.15
unnamed: Y2.1, Y2.1.1, Y2.2.1
unnamed: R25.2, Y2.2
unnamed: Y2.3, Y2.1.3, Y2.2.3
unnamed: R26.2, Y2.4
unnamed: Y2.5, Y2.1.5, Y2.2.5
unnamed: R27.2, Y2.6
unnamed: Y2.7, Y2.1.7, Y2.2.7
unnamed: R28.2, Y2.8
unnamed: Y2.9, Y2.1.9, Y2.2.9
unnamed: R29.2, Y2.10
unnamed: Y2.11, Y2.1.11, Y2.2.11
unnamed: R30.2, Y2.12
unnamed: Y2.13, Y2.1.13, Y2.2.13
unnamed: R31.2, Y2.14
unnamed: Y2.15, Y2.1.15, Y2.2.15
unnamed: R32.2, Y2.16
unnamed: R25.1, Y2.1.2, Y2.2.2
unnamed: R26.1, Y2.1.4, Y2.2.4
unnamed: R27.1, Y2.1.6, Y2.2.6
unnamed: R28.1, Y2.1.8, Y2.2.8
unnamed: R29.1, Y2.1.10, Y2.2.10
unnamed: R30.1, Y2.1.12, Y2.2.12
unnamed: R31.1, Y2.1.14, Y2.2.14
unnamed: R32.1, Y2.1.16, Y2.2.16


Board: 2 copper layers, 64.0 x 64.0 mm, 44 parts (0 on the bottom side), 96 nets.

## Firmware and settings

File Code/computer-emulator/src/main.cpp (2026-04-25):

#include <Arduino.h>

#define MAD_IN_PIN 0
#define WRITE_PIN 1

// #define RST_PIN 2
// #define X_PIN 3
// #define Y_PIN 4

const pin_size_t bus[] = {2,3,4,5,6,7,8,9};

// class Pulse{
//   private:
//     pin_size_t pin;

//   public:
//     volatile uint32_t rise_time;
//     volatile uint16_t pulse_time;
//     volatile bool pulsed = false;

//     Pulse(pin_size_t pin, voidFuncPtr callback){
//       pinMode(pin, INPUT_PULLDOWN);
//       attachInterrupt(digitalPinToInterrupt(pin), callback, CHANGE);
//     }

//     void callback(){
//       if(digitalRead(pin))
//         rise_time = micros();
//       else {
//         pulse_time = micros() - rise_time;
//         pulsed = true;
//       }
//     }

//     void reset(){
//       pulsed = false;
//     }
// };

// void rst_callback();
// void x_callback();
// void y_callback();

// Pulse rst = Pulse(RST_PIN, rst_callback);
// Pulse x = Pulse(X_PIN, x_callback);
// Pulse y = Pulse(Y_PIN, y_callback);

// void rst_callback(){rst.callback();}
// void x_callback(){x.callback();}
// void y_callback(){y.callback();}

void setup() {
  pinMode(MAD_IN_PIN, OUTPUT);
  pinMode(WRITE_PIN, OUTPUT);

  SerialUSB.setTimeout(4294967295);
  SerialUSB.begin(115200);


  for(pin_size_t pin : bus) {
    pinMode(pin, OUTPUT);
  }
}

void write_to_bus(uint8_t val){
  for(int i = 0; i < 8; i++){
    digitalWrite(bus[i], (val >> i) & 0b1);
  }
}

// void reset_all_pulses(){
//   rst.reset();
//   x.reset();
//   y.reset();
// }

void loop() {
  // reset_all_pulses();
  // digitalWrite(MAD_IN_PIN, HIGH);
  // sleep_ms(1000);
  // digitalWrite(MAD_IN_PIN, LOW);

  // SerialUSB.println("MAD In:");
  // SerialUSB.println("Times:");
  // SerialUSB.print(" - RST: ");
  // SerialUSB.println(rst.pulsed ? String(x.pulse_time) : "Didn't pulse");
  // SerialUSB.println(" - X: " + x.pulsed ? String(x.pulse_time) : "Didn't pulse :(");
  // SerialUSB.println(" - Y: " + y.pulsed ? String(y.pulse_time) : "Didn't pulse :(");
  // if(x.pulsed && y.pulsed)
  //   SerialUSB.println(" - XY Offset: " + String(y.rise_time - x.rise_time));
  SerialUSB.print("Enter an address: ");
  String input = SerialUSB.readStringUntil('\n');
  uint8_t addr = input.toInt();
  SerialUSB.println("Writing " + String(addr) + " to memory...");
  write_to_bus(addr);
  digitalWrite(MAD_IN_PIN, HIGH);
  sleep_ms(20);
  digitalWrite(MAD_IN_PIN, LOW);
  SerialUSB.println("Done!");
  SerialUSB.println();

  // digitalWrite(MAD_IN_PIN, HIGH);
  // sleep_ms(100);
  // digitalWrite(MAD_IN_PIN, LOW);
  // sleep_ms(200);
  // digitalWrite(WRITE_PIN, HIGH);
  // sleep_ms(100);
  // digitalWrite(WRITE_PIN, LOW);
  // sleep_ms(200);
}

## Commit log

2024-01-24 refactored some things
    [BOM.csv, PickAndPlace.csv]
2024-01-24 refactored and made the logic schematic more readable
    [BOM.csv, PickAndPlace.csv]
2024-02-03 Worked on Part Selection
    [Prices.ods]
2024-02-17 updated prices
    [BOM.csv, Logic Circuit.kicad_pcb, Logic Circuit.kicad_sch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]
2024-02-17 updated comps
    [Prices.ods]
2026-04-25 working magnetic core memorygit add .
    [Core Holder-B_Cu.gbr, Core Holder-B_Mask.gbr, Core Holder-B_Paste.gbr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]
2026-04-25 cleaned up code
    [Core Holder-B_Cu.gbr, Core Holder-B_Mask.gbr, Core Holder-B_Paste.gbr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]
2026-04-25 updated stuff
    [H Bridge Test.kicad_pcb, H Bridge Test.kicad_sch, Pulse Gen.kicad_pcb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]
